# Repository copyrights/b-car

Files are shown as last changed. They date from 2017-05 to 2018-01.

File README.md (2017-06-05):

# b-car
Take a classic Big Bobby Car, cut a hole in the underbody, drill some more holes, put some RGB-LEDs, buttons and a sensor through holes, place a battery and a circuit board inside and you ready to go.

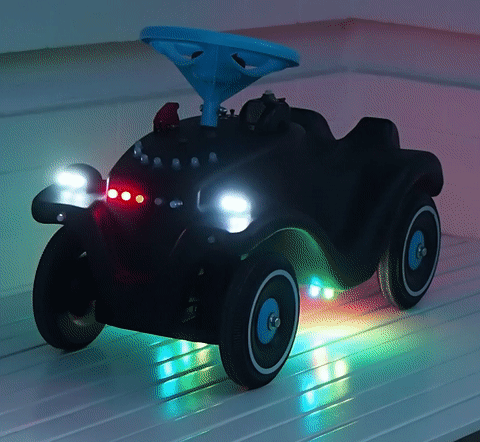
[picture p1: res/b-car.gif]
b-car GIF
   

You could use project as base for your own Bobby Car, bicycle or what ever. Get creative.
## Features
* Knight Rider like front row
* full control
  * connect up to 10 button (+power button)
  * program via USB
  * write our own program with Arduino IDE 1.6.5+ (Arduino 1.6.5r2 - NOT 1.6.6 or 1.6.7 strongly recommended) 
* tachometer
  * three colors
  * show real speed via photo sensor at a tire
* car basics
  * low beam
  * high beam 
  * back light
  * turn lights
* flash light
* police beacon light an front flash
* rainbow mode

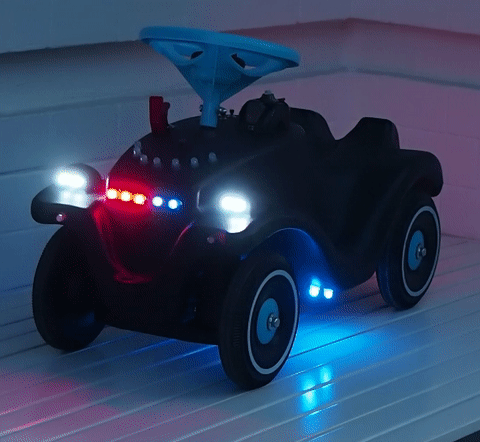
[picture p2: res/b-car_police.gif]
b-car police mode GIF
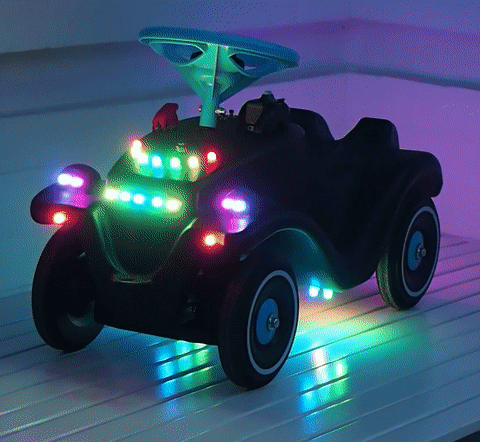
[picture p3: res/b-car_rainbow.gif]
b-car rainbow GIF
 
## Hardware
### Circuit 

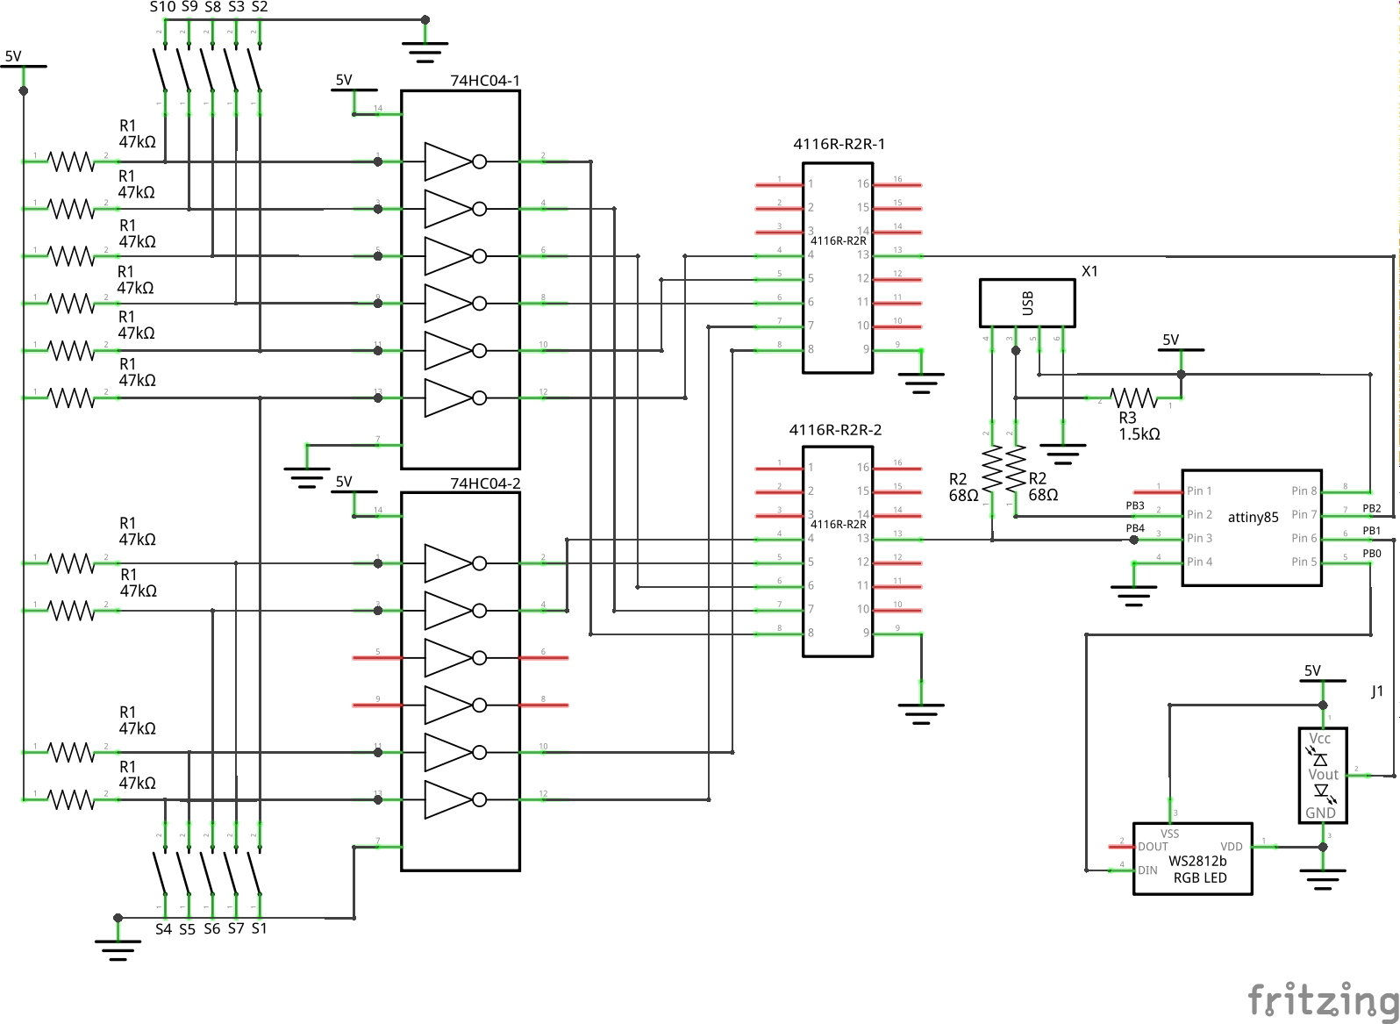
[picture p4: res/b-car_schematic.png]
schematic


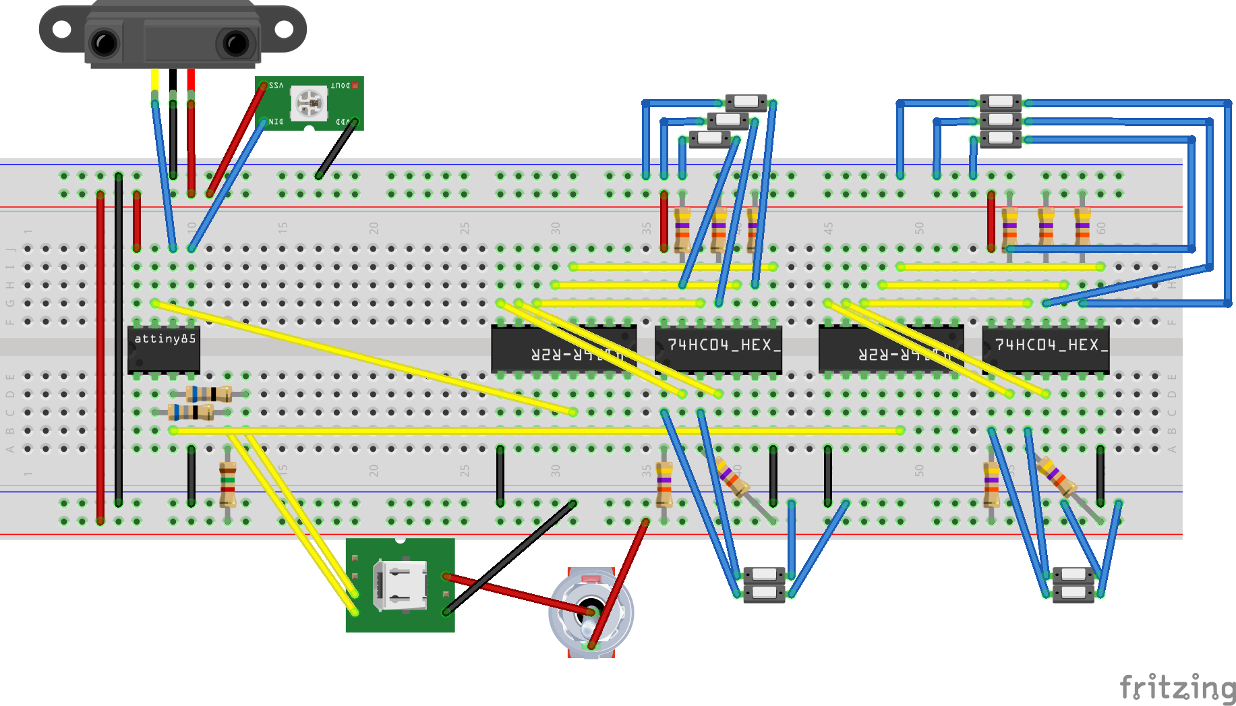
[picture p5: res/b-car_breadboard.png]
bread board


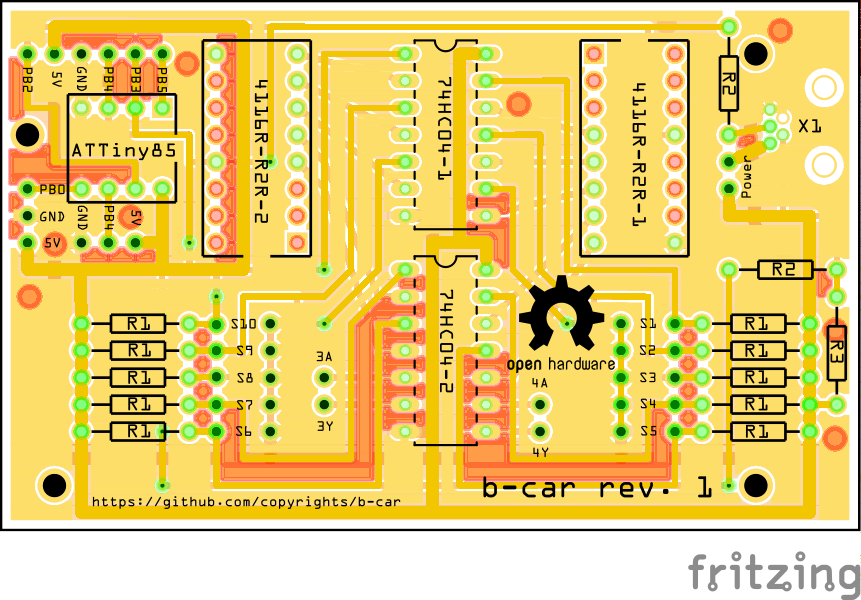
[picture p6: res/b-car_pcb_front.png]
pcb front side


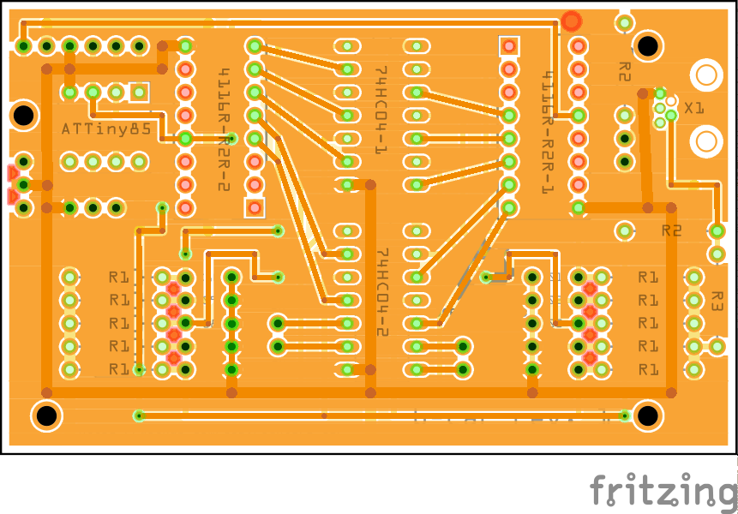
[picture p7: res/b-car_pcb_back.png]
pcb back side


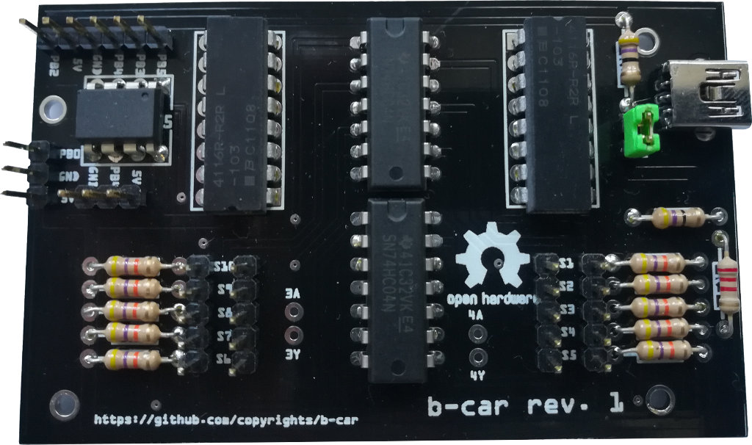
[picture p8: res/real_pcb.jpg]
final board

### Bobby Car 

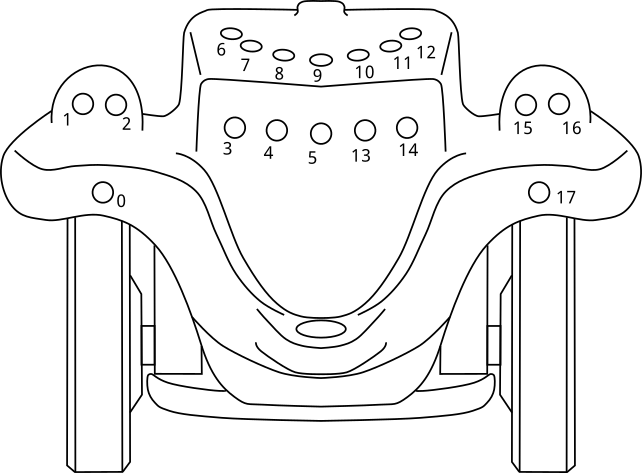
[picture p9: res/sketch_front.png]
sketch front


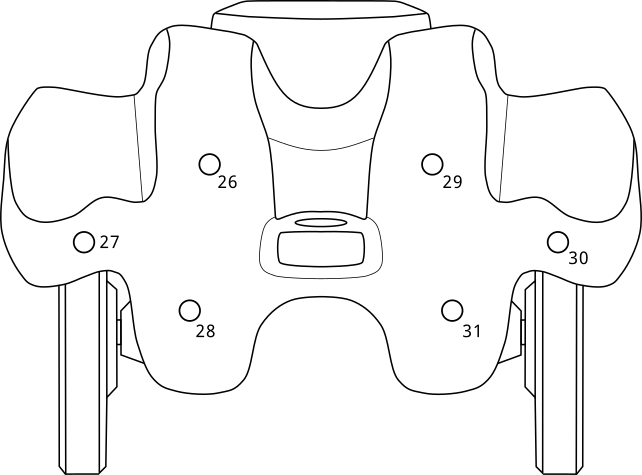
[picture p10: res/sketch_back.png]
Sketch front


## Software
The b-car runs the [micronucleus tiny85](https://github.com/micronucleus/micronucleus) bootloader.

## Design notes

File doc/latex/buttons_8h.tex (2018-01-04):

\hypertarget{buttons_8h}{}\section{buttons.\+h File Reference}
\label{buttons_8h}\index{buttons.\+h@{buttons.\+h}}
{\ttfamily \#include \char`\"{}config.\+h\char`\"{}}\\*
Include dependency graph for buttons.\+h\+:\nopagebreak
\begin{figure}[H]
\begin{center}
\leavevmode
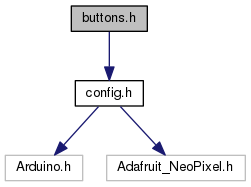
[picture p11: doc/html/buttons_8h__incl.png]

\end{center}
\end{figure}
This graph shows which files directly or indirectly include this file\+:\nopagebreak
\begin{figure}[H]
\begin{center}
\leavevmode
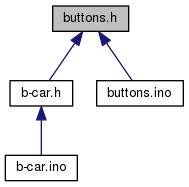
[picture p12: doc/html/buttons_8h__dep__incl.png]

\end{center}
\end{figure}
\subsection*{Functions}
\begin{DoxyCompactItemize}
\item 
void \hyperlink{buttons_8h_af32fa88edc93b34e25f058e331ea1134}{update\+Buttons} ()
\begin{DoxyCompactList}\small\item\em Read button state and calculate stable button state. \end{DoxyCompactList}\item 
bool \hyperlink{buttons_8h_ad4a8f6035320735a6ed69364c0f29d63}{button\+State} (uint16\+\_\+t mask)
\begin{DoxyCompactList}\small\item\em Returns the state of a button as boolean. \end{DoxyCompactList}\item 
uint16\+\_\+t \hyperlink{buttons_8h_a5421761bb5d1c3470d3b17196a438c80}{readr2r} (int pin)
\begin{DoxyCompactList}\small\item\em Calculated the current button state as a 5 bit mask. \end{DoxyCompactList}\item 
uint16\+\_\+t \hyperlink{buttons_8h_a0ce7c5a698df341a0f3882378518f562}{debounce} (uint16\+\_\+t curbuttons)
\begin{DoxyCompactList}\small\item\em Debounce button presses of the R-\/2R resistor ladder network. \end{DoxyCompactList}\item 
void \hyperlink{buttons_8h_a66c6a02c014dc9acd3af0c816a70fad8}{updintr} (uint16\+\_\+t state)
\begin{DoxyCompactList}\small\item\em Update the simulated interrupts of the R-\/2R resistor ladder network. \end{DoxyCompactList}\item 
uint16\+\_\+t \hyperlink{buttons_8h_a9b1decfe9116af4b8853a02aebfa1d14}{get\+Rising} (uint16\+\_\+t mask)
\begin{DoxyCompactList}\small\item\em Get simulated rising edge interrupt(s) for simulated interrupt service routine. \end{DoxyCompactList}\item 
uint16\+\_\+t \hyperlink{buttons_8h_a2971d62e0d7420f71836fb86e0fce92f}{get\+Falling} (uint16\+\_\+t mask)
\begin{DoxyCompactList}\small\item\em Get simulated falling edge interrupt(s) for simulated interrupt service routine. \end{DoxyCompactList}\end{DoxyCompactItemize}
\subsection*{Variables}
\begin{DoxyCompactItemize}
\item 
uint16\+\_\+t \hyperlink{group__buttons_gac23a04180ca7609f571853499faae915}{lastbuttons}
\begin{DoxyCompactList}\small\item\em Last read of button pressed. \end{DoxyCompactList}\item 
uint16\+\_\+t \hyperlink{buttons_8h_aca8bc953fb5340b58c9403b3bf8bbd8e}{stablebuttons}
\begin{DoxyCompactList}\small\item\em Pressed Buttons after debounce. \end{DoxyCompactList}\item 
uint16\+\_\+t \hyperlink{buttons_8h_ac52f8abe18e87b9ce8cdba2e27bbbf02}{buttonstore}
\begin{DoxyCompactList}\small\item\em Stores push buttons as simulated toggle buttons. \end{DoxyCompactList}\item 
uint16\+\_\+t \hyperlink{buttons_8h_afa19e52bd127439ef22ade9f91753386}{buttonstate}
\begin{DoxyCompactList}\small\item\em Stores current button state with simulated toggle buttons included. \end{DoxyCompactList}\item 
uint16\+\_\+t \hyperlink{buttons_8h_acc4c256fa5e75c09f1b3a669d45485ec}{rising}
\begin{DoxyCompactList}\small\item\em Stores simulated interrupts for rising edge. \end{DoxyCompactList}\item 
uint16\+\_\+t \hyperlink{buttons_8h_a1861b594f36400f6c17b1f65b2565816}{falling}
\begin{DoxyCompactList}\small\item\em Stores simulated interrupts for falling edge. \end{DoxyCompactList}\item 
uint16\+\_\+t \hyperlink{buttons_8h_a541db091bf54e0a51180f3666e5a2ce2}{rfilter}
\begin{DoxyCompactList}\small\item\em Filter for simulated interrupts for rising edge. \end{DoxyCompactList}\item 
uint16\+\_\+t \hyperlink{buttons_8h_aaa75cede053f94cf46d7420556af1505}{ffilter}
\begin{DoxyCompactList}\small\item\em Filter for simulated interrupts for falling edge. \end{DoxyCompactList}\item 
unsigned long \hyperlink{buttons_8h_a94921f7ca95d518d3deabb1da432c2fb}{dtime}
\begin{DoxyCompactList}\small\item\em Store the time of the last debounce to calculate delta time to next debounce. \end{DoxyCompactList}\end{DoxyCompactItemize}

\subsection{Function Documentation}
\index{buttons.\+h@{buttons.\+h}!button\+State@{button\+State}}
\index{button\+State@{button\+State}!buttons.\+h@{buttons.\+h}}
\subsubsection[{\texorpdfstring{button\+State(uint16\+\_\+t mask)}{buttonState(uint16_t mask)}}]{\setlength{\rightskip}{0pt plus 5cm}bool button\+State (
\begin{DoxyParamCaption}
\item[{uint16\+\_\+t}]{mask}
\end{DoxyParamCaption}
)}\hypertarget{buttons_8h_ad4a8f6035320735a6ed69364c0f29d63}{}\label{buttons_8h_ad4a8f6035320735a6ed69364c0f29d63}

Returns the state of a button as boolean. 

\begin{DoxyParams}{Parameters}
{\em mask} & Button of interested. \\
\hline
\end{DoxyParams}
\begin{DoxyReturn}{Returns}
Returns true, if button is pressed. Returns false, if it is not pressed. 
\end{DoxyReturn}

Definition at line 50 of file buttons.\+ino.

\index{buttons.\+h@{buttons.\+h}!debounce@{debounce}}
\index{debounce@{debounce}!buttons.\+h@{buttons.\+h}}
\subsubsection[{\texorpdfstring{debounce(uint16\+\_\+t curbuttons)}{debounce(uint16_t curbuttons)}}]{\setlength{\rightskip}{0pt plus 5cm}uint16\+\_\+t debounce (
\begin{DoxyParamCaption}
\item[{uint16\+\_\+t}]{curbuttons}
\end{DoxyParamCaption}
)}\hypertarget{buttons_8h_a0ce7c5a698df341a0f3882378518f562}{}\label{buttons_8h_a0ce7c5a698df341a0f3882378518f562}

Debounce button presses of the R-\/2R resistor ladder network. 

\begin{DoxyParams}{Parameters}
{\em curbuttons} & Bit mask of current button state. \\
\hline
\end{DoxyParams}
\begin{DoxyReturn}{Returns}
Bit mask of debounced button state. 
\end{DoxyReturn}

Definition at line 79 of file buttons.\+ino.

\index{buttons.\+h@{buttons.\+h}!get\+Falling@{get\+Falling}}
\index{get\+Falling@{get\+Falling}!buttons.\+h@{buttons.\+h}}
\subsubsection[{\texorpdfstring{get\+Falling(uint16\+\_\+t mask)}{getFalling(uint16_t mask)}}]{\setlength{\rightskip}{0pt plus 5cm}uint16\+\_\+t get\+Falling (
\begin{DoxyParamCaption}
\item[{uint16\+\_\+t}]{mask}
\end{DoxyParamCaption}
)}\hypertarget{buttons_8h_a2971d62e0d7420f71836fb86e0fce92f}{}\label{buttons_8h_a2971d62e0d7420f71836fb86e0fce92f}

Get simulated falling edge interrupt(s) for simulated interrupt service routine. 

\begin{DoxyParams}{Parameters}
{\em mask} & Button(s) of interest. \\
\hline
\end{DoxyParams}
\begin{DoxyReturn}{Returns}
Bit mask of interrupt(s). 
\end{DoxyReturn}

Definition at line 129 of file buttons.\+ino.

\index{buttons.\+h@{buttons.\+h}!get\+Rising@{get\+Rising}}
\index{get\+Rising@{get\+Rising}!buttons.\+h@{buttons.\+h}}
\subsubsection[{\texorpdfstring{get\+Rising(uint16\+\_\+t mask)}{getRising(uint16_t mask)}}]{\setlength{\rightskip}{0pt plus 5cm}uint16\+\_\+t get\+Rising (
\begin{DoxyParamCaption}
\item[{uint16\+\_\+t}]{mask}
\end{DoxyParamCaption}
)}\hypertarget{buttons_8h_a9b1decfe9116af4b8853a02aebfa1d14}{}\label{buttons_8h_a9b1decfe9116af4b8853a02aebfa1d14}

Get simulated rising edge interrupt(s) for simulated interrupt service routine. 

\begin{DoxyParams}{Parameters}
{\em mask} & Button(s) of interest. \\
\hline
\end{DoxyParams}
\begin{DoxyReturn}{Returns}
Bit mask of interrupt(s). 
\end{DoxyReturn}

Definition at line 115 of file buttons.\+ino.

\index{buttons.\+h@{buttons.\+h}!readr2r@{readr2r}}
\index{readr2r@{readr2r}!buttons.\+h@{buttons.\+h}}
\subsubsection[{\texorpdfstring{readr2r(int pin)}{readr2r(int pin)}}]{\setlength{\rightskip}{0pt plus 5cm}uint16\+\_\+t readr2r (
\begin{DoxyParamCaption}
\item[{int}]{pin}
\end{DoxyParamCaption}
)}\hypertarget{buttons_8h_a5421761bb5d1c3470d3b17196a438c80}{}\label{buttons_8h_a5421761bb5d1c3470d3b17196a438c80}

Calculated the current button state as a 5 bit mask. 

\begin{DoxyParams}{Parameters}
{\em pin} & Analog input pin connected to a R-\/2R resistor ladder network. \\
\hline
\end{DoxyParams}
\begin{DoxyReturn}{Returns}
Current button state as 5 bit mask. 
\end{DoxyReturn}

Definition at line 61 of file buttons.\+ino.

\index{buttons.\+h@{buttons.\+h}!update\+Buttons@{update\+Buttons}}
\index{update\+Buttons@{update\+Buttons}!buttons.\+h@{buttons.\+h}}
\subsubsection[{\texorpdfstring{update\+Buttons()}{updateButtons()}}]{\setlength{\rightskip}{0pt plus 5cm}void update\+Buttons (
\begin{DoxyParamCaption}
{}
\end{DoxyParamCaption}
)}\hypertarget{buttons_8h_af32fa88edc93b34e25f058e331ea1134}{}\label{buttons_8h_af32fa88edc93b34e25f058e331ea1134}

Read button state and calculate stable button state. 

Definition at line 33 of file buttons.\+ino.

\index{buttons.\+h@{buttons.\+h}!updintr@{updintr}}
\index{updintr@{updintr}!buttons.\+h@{buttons.\+h}}
\subsubsection[{\texorpdfstring{updintr(uint16\+\_\+t state)}{updintr(uint16_t state)}}]{\setlength{\rightskip}{0pt plus 5cm}void updintr (
\begin{DoxyParamCaption}
\item[{uint16\+\_\+t}]{state}
\end{DoxyParamCaption}
)}\hypertarget{buttons_8h_a66c6a02c014dc9acd3af0c816a70fad8}{}\label{buttons_8h_a66c6a02c014dc9acd3af0c816a70fad8}

Update the simulated interrupts of the R-\/2R resistor ladder network. 

\begin{DoxyParams}{Parameters}
{\em state} & Bit mask of current button state. \\
\hline
\end{DoxyParams}

Definition at line 101 of file buttons.\+ino.

\subsection{Variable Documentation}
\index{buttons.\+h@{buttons.\+h}!buttonstate@{buttonstate}}
\index{buttonstate@{buttonstate}!buttons.\+h@{buttons.\+h}}
\subsubsection[{\texorpdfstring{buttonstate}{buttonstate}}]{\setlength{\rightskip}{0pt plus 5cm}uint16\+\_\+t buttonstate}\hypertarget{buttons_8h_afa19e52bd127439ef22ade9f91753386}{}\label{buttons_8h_afa19e52bd127439ef22ade9f91753386}

Stores current button state with simulated toggle buttons included. 

Definition at line 20 of file buttons.\+ino.

\index{buttons.\+h@{buttons.\+h}!buttonstore@{buttonstore}}
\index{buttonstore@{buttonstore}!buttons.\+h@{buttons.\+h}}
\subsubsection[{\texorpdfstring{buttonstore}{buttonstore}}]{\setlength{\rightskip}{0pt plus 5cm}uint16\+\_\+t buttonstore}\hypertarget{buttons_8h_ac52f8abe18e87b9ce8cdba2e27bbbf02}{}\label{buttons_8h_ac52f8abe18e87b9ce8cdba2e27bbbf02}

Stores push buttons as simulated toggle buttons. 

Definition at line 18 of file buttons.\+ino.

\index{buttons.\+h@{buttons.\+h}!dtime@{dtime}}
\index{dtime@{dtime}!buttons.\+h@{buttons.\+h}}
\subsubsection[{\texorpdfstring{dtime}{dtime}}]{\setlength{\rightskip}{0pt plus 5cm}unsigned long dtime}\hypertarget{buttons_8h_a94921f7ca95d518d3deabb1da432c2fb}{}\label{buttons_8h_a94921f7ca95d518d3deabb1da432c2fb}

Store the time of the last debounce to calculate delta time to next debounce. 

Definition at line 30 of file buttons.\+ino.

\index{buttons.\+h@{buttons.\+h}!falling@{falling}}
\index{falling@{falling}!buttons.\+h@{buttons.\+h}}
\subsubsection[{\texorpdfstring{falling}{falling}}]{\setlength{\rightskip}{0pt plus 5cm}uint16\+\_\+t falling}\hypertarget{buttons_8h_a1861b594f36400f6c17b1f65b2565816}{}\label{buttons_8h_a1861b594f36400f6c17b1f65b2565816}

Stores simulated interrupts for falling edge. 

Definition at line 24 of file buttons.\+ino.

\index{buttons.\+h@{buttons.\+h}!ffilter@{ffilter}}
\index{ffilter@{ffilter}!buttons.\+h@{buttons.\+h}}
\subsubsection[{\texorpdfstring{ffilter}{ffilter}}]{\setlength{\rightskip}{0pt plus 5cm}uint16\+\_\+t ffilter}\hypertarget{buttons_8h_aaa75cede053f94cf46d7420556af1505}{}\label{buttons_8h_aaa75cede053f94cf46d7420556af1505}

Filter for simulated interrupts for falling edge. 

Definition at line 28 of file buttons.\+ino.

\index{buttons.\+h@{buttons.\+h}!rfilter@{rfilter}}
\index{rfilter@{rfilter}!buttons.\+h@{buttons.\+h}}
\subsubsection[{\texorpdfstring{rfilter}{rfilter}}]{\setlength{\rightskip}{0pt plus 5cm}uint16\+\_\+t rfilter}\hypertarget{buttons_8h_a541db091bf54e0a51180f3666e5a2ce2}{}\label{buttons_8h_a541db091bf54e0a51180f3666e5a2ce2}

Filter for simulated interrupts for rising edge. 

Definition at line 26 of file buttons.\+ino.

\index{buttons.\+h@{buttons.\+h}!rising@{rising}}
\index{rising@{rising}!buttons.\+h@{buttons.\+h}}
\subsubsection[{\texorpdfstring{rising}{rising}}]{\setlength{\rightskip}{0pt plus 5cm}uint16\+\_\+t rising}\hypertarget{buttons_8h_acc4c256fa5e75c09f1b3a669d45485ec}{}\label{buttons_8h_acc4c256fa5e75c09f1b3a669d45485ec}

Stores simulated interrupts for rising edge. 

Definition at line 22 of file buttons.\+ino.

\index{buttons.\+h@{buttons.\+h}!stablebuttons@{stablebuttons}}
\index{stablebuttons@{stablebuttons}!buttons.\+h@{buttons.\+h}}
\subsubsection[{\texorpdfstring{stablebuttons}{stablebuttons}}]{\setlength{\rightskip}{0pt plus 5cm}uint16\+\_\+t stablebuttons}\hypertarget{buttons_8h_aca8bc953fb5340b58c9403b3bf8bbd8e}{}\label{buttons_8h_aca8bc953fb5340b58c9403b3bf8bbd8e}

Pressed Buttons after debounce. 

Definition at line 16 of file buttons.\+ino.

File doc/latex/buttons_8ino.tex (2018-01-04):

\hypertarget{buttons_8ino}{}\section{buttons.\+ino File Reference}
\label{buttons_8ino}\index{buttons.\+ino@{buttons.\+ino}}

Use two R-\/2R resistor ladder networks to connect up to 10 buttons on two analog inputs.  

{\ttfamily \#include \char`\"{}buttons.\+h\char`\"{}}\\*
Include dependency graph for buttons.\+ino\+:\nopagebreak
\begin{figure}[H]
\begin{center}
\leavevmode
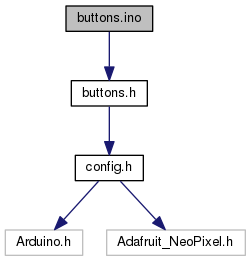
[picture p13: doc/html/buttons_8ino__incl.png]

\end{center}
\end{figure}
\begin{DoxyCompactItemize}
\item 
uint16\+\_\+t \hyperlink{group__buttons_gac23a04180ca7609f571853499faae915}{lastbuttons} = 0
\begin{DoxyCompactList}\small\item\em Last read of button pressed. \end{DoxyCompactList}\item 
uint16\+\_\+t \hyperlink{group__buttons_gaca8bc953fb5340b58c9403b3bf8bbd8e}{stablebuttons} = 0
\begin{DoxyCompactList}\small\item\em Pressed Buttons after debounce. \end{DoxyCompactList}\item 
uint16\+\_\+t \hyperlink{group__buttons_gac52f8abe18e87b9ce8cdba2e27bbbf02}{buttonstore} = \hyperlink{group__buttons_ga77a6549a849f9a9472a367e4148289b7}{T\+O\+G\+G\+L\+E\+M\+A\+SK}
\begin{DoxyCompactList}\small\item\em Stores push buttons as simulated toggle buttons. \end{DoxyCompactList}\item 
uint16\+\_\+t \hyperlink{group__buttons_gafa19e52bd127439ef22ade9f91753386}{buttonstate} = 0
\begin{DoxyCompactList}\small\item\em Stores current button state with simulated toggle buttons included. \end{DoxyCompactList}\item 
uint16\+\_\+t \hyperlink{group__buttons_gacc4c256fa5e75c09f1b3a669d45485ec}{rising} = 0
\begin{DoxyCompactList}\small\item\em Stores simulated interrupts for rising edge. \end{DoxyCompactList}\item 
uint16\+\_\+t \hyperlink{group__buttons_ga1861b594f36400f6c17b1f65b2565816}{falling} = 0
\begin{DoxyCompactList}\small\item\em Stores simulated interrupts for falling edge. \end{DoxyCompactList}\item 
uint16\+\_\+t \hyperlink{group__buttons_ga541db091bf54e0a51180f3666e5a2ce2}{rfilter} = 0
\begin{DoxyCompactList}\small\item\em Filter for simulated interrupts for rising edge. \end{DoxyCompactList}\item 
uint16\+\_\+t \hyperlink{group__buttons_gaaa75cede053f94cf46d7420556af1505}{ffilter} = 0
\begin{DoxyCompactList}\small\item\em Filter for simulated interrupts for falling edge. \end{DoxyCompactList}\item 
unsigned long \hyperlink{group__buttons_ga94921f7ca95d518d3deabb1da432c2fb}{dtime} = 0
\begin{DoxyCompactList}\small\item\em Store the time of the last debounce to calculate delta time to next debounce. \end{DoxyCompactList}\item 
void \hyperlink{group__buttons_gaf32fa88edc93b34e25f058e331ea1134}{update\+Buttons} ()
\begin{DoxyCompactList}\small\item\em Read button state and calculate stable button state. \end{DoxyCompactList}\item 
bool \hyperlink{group__buttons_gad4a8f6035320735a6ed69364c0f29d63}{button\+State} (uint16\+\_\+t mask)
\begin{DoxyCompactList}\small\item\em Returns the state of a button as boolean. \end{DoxyCompactList}\item 
uint16\+\_\+t \hyperlink{group__buttons_ga5421761bb5d1c3470d3b17196a438c80}{readr2r} (int pin)
\begin{DoxyCompactList}\small\item\em Calculated the current button state as a 5 bit mask. \end{DoxyCompactList}\item 
uint16\+\_\+t \hyperlink{group__buttons_ga0ce7c5a698df341a0f3882378518f562}{debounce} (uint16\+\_\+t curbuttons)
\begin{DoxyCompactList}\small\item\em Debounce button presses of the R-\/2R resistor ladder network. \end{DoxyCompactList}\item 
void \hyperlink{group__buttons_ga66c6a02c014dc9acd3af0c816a70fad8}{updintr} (uint16\+\_\+t state)
\begin{DoxyCompactList}\small\item\em Update the simulated interrupts of the R-\/2R resistor ladder network. \end{DoxyCompactList}\item 
uint16\+\_\+t \hyperlink{group__buttons_ga9b1decfe9116af4b8853a02aebfa1d14}{get\+Rising} (uint16\+\_\+t mask)
\begin{DoxyCompactList}\small\item\em Get simulated rising edge interrupt(s) for simulated interrupt service routine. \end{DoxyCompactList}\item 
uint16\+\_\+t \hyperlink{group__buttons_ga2971d62e0d7420f71836fb86e0fce92f}{get\+Falling} (uint16\+\_\+t mask)
\begin{DoxyCompactList}\small\item\em Get simulated falling edge interrupt(s) for simulated interrupt service routine. \end{DoxyCompactList}\end{DoxyCompactItemize}

\subsection{Detailed Description}
Use two R-\/2R resistor ladder networks to connect up to 10 buttons on two analog inputs. 

\begin{DoxyAuthor}{Author}
copyrights
\end{DoxyAuthor}
\begin{DoxySeeAlso}{See also}
\href{https://en.wikipedia.org/wiki/Resistor_ladder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}{\tt https\+://en.\+wikipedia.\+org/wiki/\+Resistor\+\_\+ladder\#\+R.\+E2.\+80.\+932\+R\+\_\+resistor\+\_\+ladder\+\_\+network\+\_\+.\+28digital\+\_\+to\+\_\+analog\+\_\+conversion.\+29} 
\end{DoxySeeAlso}

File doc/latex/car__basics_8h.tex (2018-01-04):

\hypertarget{car__basics_8h}{}\section{car\+\_\+basics.\+h File Reference}
\label{car__basics_8h}\index{car\+\_\+basics.\+h@{car\+\_\+basics.\+h}}
{\ttfamily \#include \char`\"{}config.\+h\char`\"{}}\\*
Include dependency graph for car\+\_\+basics.\+h\+:\nopagebreak
\begin{figure}[H]
\begin{center}
\leavevmode
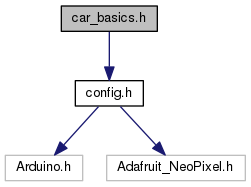
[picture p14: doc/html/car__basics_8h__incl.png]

\end{center}
\end{figure}
This graph shows which files directly or indirectly include this file\+:\nopagebreak
\begin{figure}[H]
\begin{center}
\leavevmode
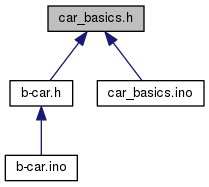
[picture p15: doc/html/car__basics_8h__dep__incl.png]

\end{center}
\end{figure}
\subsection*{Functions}
\begin{DoxyCompactItemize}
\item 
void \hyperlink{car__basics_8h_aca3b725ebee32d3719a9c02b41002ea3}{turn\+\_\+right} ()
\begin{DoxyCompactList}\small\item\em Activate right turn lights. \end{DoxyCompactList}\item 
void \hyperlink{car__basics_8h_a0565ad7a822d9d334bb50c088af22361}{turn\+\_\+left} ()
\begin{DoxyCompactList}\small\item\em Activate left turn lights. \end{DoxyCompactList}\item 
void \hyperlink{car__basics_8h_a6b1fd674445dd1c654dfe8b8b65f168e}{beam} (unsigned long state)
\begin{DoxyCompactList}\small\item\em Activate low beam or high beam. \end{DoxyCompactList}\item 
void \hyperlink{car__basics_8h_a29d5eff542aae0196b8e84b8a752e1df}{low\+\_\+beam} (bool on)
\item 
void \hyperlink{car__basics_8h_a1088d06b4ab015d579e0ac2510d39f25}{high\+\_\+beam} (bool on)
\item 
void \hyperlink{car__basics_8h_ac7295d1018b2b948084ba5dbacf09d74}{tacho} ()
\begin{DoxyCompactList}\small\item\em Display the current speed on tacho\+\_\+row L\+E\+Ds. \end{DoxyCompactList}\item 
void \hyperlink{car__basics_8h_affb7c011f82f3fb47b39ebb2713a1cd8}{flash} ()
\begin{DoxyCompactList}\small\item\em Flash light. \end{DoxyCompactList}\item 
void \hyperlink{car__basics_8h_a1ac48972153097ad7a16fffc032fc5f1}{brakelight} ()
\begin{DoxyCompactList}\small\item\em Brake light. \end{DoxyCompactList}\end{DoxyCompactItemize}

\subsection{Function Documentation}
\index{car\+\_\+basics.\+h@{car\+\_\+basics.\+h}!beam@{beam}}
\index{beam@{beam}!car\+\_\+basics.\+h@{car\+\_\+basics.\+h}}
\subsubsection[{\texorpdfstring{beam(unsigned long state)}{beam(unsigned long state)}}]{\setlength{\rightskip}{0pt plus 5cm}void beam (
\begin{DoxyParamCaption}
\item[{unsigned long}]{state}
\end{DoxyParamCaption}
)}\hypertarget{car__basics_8h_a6b1fd674445dd1c654dfe8b8b65f168e}{}\label{car__basics_8h_a6b1fd674445dd1c654dfe8b8b65f168e}

Activate low beam or high beam. 

\begin{DoxyRefDesc}{Todo}
\item[\hyperlink{todo__todo000002}{Todo}]Rewrite as all L\+E\+Ds get clear at the beginning of the main loop \end{DoxyRefDesc}

Definition at line 59 of file car\+\_\+basics.\+ino.

\index{car\+\_\+basics.\+h@{car\+\_\+basics.\+h}!brakelight@{brakelight}}
\index{brakelight@{brakelight}!car\+\_\+basics.\+h@{car\+\_\+basics.\+h}}
\subsubsection[{\texorpdfstring{brakelight()}{brakelight()}}]{\setlength{\rightskip}{0pt plus 5cm}void brakelight (
\begin{DoxyParamCaption}
{}
\end{DoxyParamCaption}
)}\hypertarget{car__basics_8h_a1ac48972153097ad7a16fffc032fc5f1}{}\label{car__basics_8h_a1ac48972153097ad7a16fffc032fc5f1}

Brake light. 

Put \hyperlink{group__deployment_ga3a2101866267bf0af2559a241cdb7cc6}{back\+\_\+light\+\_\+row} to \hyperlink{group__car_ga95743a8e9ccb3be5a627dd9322806751}{B\+R\+A\+K\+E\+L\+I\+G\+HT}. 

Definition at line 184 of file car\+\_\+basics.\+ino.

\index{car\+\_\+basics.\+h@{car\+\_\+basics.\+h}!flash@{flash}}
\index{flash@{flash}!car\+\_\+basics.\+h@{car\+\_\+basics.\+h}}
\subsubsection[{\texorpdfstring{flash()}{flash()}}]{\setlength{\rightskip}{0pt plus 5cm}void flash (
\begin{DoxyParamCaption}
{}
\end{DoxyParamCaption}
)}\hypertarget{car__basics_8h_affb7c011f82f3fb47b39ebb2713a1cd8}{}\label{car__basics_8h_affb7c011f82f3fb47b39ebb2713a1cd8}

Flash light. 

Put \hyperlink{group__deployment_ga8b165874b487053cb404215a7f42e33e}{high\+\_\+beam\+\_\+row}, \hyperlink{group__deployment_ga848556a6e145736d917b4f0a67ee60ae}{front\+\_\+row} and \hyperlink{group__deployment_ga3a2101866267bf0af2559a241cdb7cc6}{back\+\_\+light\+\_\+row} to \hyperlink{group__car_ga3f561f12573270e4b5329bc5930ad20f}{H\+I\+G\+H\+B\+E\+AM}. 

Definition at line 164 of file car\+\_\+basics.\+ino.

\index{car\+\_\+basics.\+h@{car\+\_\+basics.\+h}!high\+\_\+beam@{high\+\_\+beam}}
\index{high\+\_\+beam@{high\+\_\+beam}!car\+\_\+basics.\+h@{car\+\_\+basics.\+h}}
\subsubsection[{\texorpdfstring{high\+\_\+beam(bool on)}{high_beam(bool on)}}]{\setlength{\rightskip}{0pt plus 5cm}void high\+\_\+beam (
\begin{DoxyParamCaption}
\item[{bool}]{on}
\end{DoxyParamCaption}
)}\hypertarget{car__basics_8h_a1088d06b4ab015d579e0ac2510d39f25}{}\label{car__basics_8h_a1088d06b4ab015d579e0ac2510d39f25}

Definition at line 91 of file car\+\_\+basics.\+ino.

\index{car\+\_\+basics.\+h@{car\+\_\+basics.\+h}!low\+\_\+beam@{low\+\_\+beam}}
\index{low\+\_\+beam@{low\+\_\+beam}!car\+\_\+basics.\+h@{car\+\_\+basics.\+h}}
\subsubsection[{\texorpdfstring{low\+\_\+beam(bool on)}{low_beam(bool on)}}]{\setlength{\rightskip}{0pt plus 5cm}void low\+\_\+beam (
\begin{DoxyParamCaption}
\item[{bool}]{on}
\end{DoxyParamCaption}
)}\hypertarget{car__basics_8h_a29d5eff542aae0196b8e84b8a752e1df}{}\label{car__basics_8h_a29d5eff542aae0196b8e84b8a752e1df}

Definition at line 73 of file car\+\_\+basics.\+ino.

\index{car\+\_\+basics.\+h@{car\+\_\+basics.\+h}!tacho@{tacho}}
\index{tacho@{tacho}!car\+\_\+basics.\+h@{car\+\_\+basics.\+h}}
\subsubsection[{\texorpdfstring{tacho()}{tacho()}}]{\setlength{\rightskip}{0pt plus 5cm}void tacho (
\begin{DoxyParamCaption}
{}
\end{DoxyParamCaption}
)}\hypertarget{car__basics_8h_ac7295d1018b2b948084ba5dbacf09d74}{}\label{car__basics_8h_ac7295d1018b2b948084ba5dbacf09d74}

Display the current speed on tacho\+\_\+row L\+E\+Ds. 

It is show from left to right in three different color.

\begin{DoxyItemize}
\item Green (0x001100)\+: low speed
\item Orange (0x110800)\+: medium speed
\item Red (0x110000)\+: ludicrous speed
\end{DoxyItemize}

The function \hyperlink{speed_8h_afc7b1718f9b23966dfed24056f67996f}{getspeed()} returns an unsigned integer with a step size of 1 equals 0.\+4302 km/h. As the speed is displayed in three color the maximum speed should be dividable by three.

The integer value 30 -\/$>$ 12.\+9 km/h. 12.\+9 km/h should be enough for small children. If you have a older child or use this for different purposes (e.\+g. a bicycle), the maximum speed should be higher.

30/3 = 10 -\/$>$ speed $\ast$ count of tachometer L\+E\+Ds / 10 \begin{DoxySeeAlso}{See also}
\hyperlink{speed_8h_afc7b1718f9b23966dfed24056f67996f}{getspeed()} 
\end{DoxySeeAlso}

Definition at line 129 of file car\+\_\+basics.\+ino.

\index{car\+\_\+basics.\+h@{car\+\_\+basics.\+h}!turn\+\_\+left@{turn\+\_\+left}}
\index{turn\+\_\+left@{turn\+\_\+left}!car\+\_\+basics.\+h@{car\+\_\+basics.\+h}}
\subsubsection[{\texorpdfstring{turn\+\_\+left()}{turn_left()}}]{\setlength{\rightskip}{0pt plus 5cm}void turn\+\_\+left (
\begin{DoxyParamCaption}
{}
\end{DoxyParamCaption}
)}\hypertarget{car__basics_8h_a0565ad7a822d9d334bb50c088af22361}{}\label{car__basics_8h_a0565ad7a822d9d334bb50c088af22361}

Activate left turn lights. 

Definition at line 42 of file car\+\_\+basics.\+ino.

\index{car\+\_\+basics.\+h@{car\+\_\+basics.\+h}!turn\+\_\+right@{turn\+\_\+right}}
\index{turn\+\_\+right@{turn\+\_\+right}!car\+\_\+basics.\+h@{car\+\_\+basics.\+h}}
\subsubsection[{\texorpdfstring{turn\+\_\+right()}{turn_right()}}]{\setlength{\rightskip}{0pt plus 5cm}void turn\+\_\+right (
\begin{DoxyParamCaption}
{}
\end{DoxyParamCaption}
)}\hypertarget{car__basics_8h_aca3b725ebee32d3719a9c02b41002ea3}{}\label{car__basics_8h_aca3b725ebee32d3719a9c02b41002ea3}

Activate right turn lights. 

Definition at line 27 of file car\+\_\+basics.\+ino.

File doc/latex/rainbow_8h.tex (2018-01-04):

\hypertarget{rainbow_8h}{}\section{rainbow.\+h File Reference}
\label{rainbow_8h}\index{rainbow.\+h@{rainbow.\+h}}
{\ttfamily \#include \char`\"{}config.\+h\char`\"{}}\\*
Include dependency graph for rainbow.\+h\+:\nopagebreak
\begin{figure}[H]
\begin{center}
\leavevmode
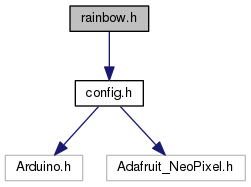
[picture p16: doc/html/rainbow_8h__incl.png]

\end{center}
\end{figure}
This graph shows which files directly or indirectly include this file\+:\nopagebreak
\begin{figure}[H]
\begin{center}
\leavevmode
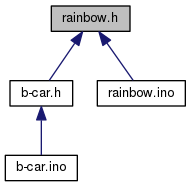
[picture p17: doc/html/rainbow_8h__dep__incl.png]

\end{center}
\end{figure}
\subsection*{Functions}
\begin{DoxyCompactItemize}
\item 
void \hyperlink{rainbow_8h_a51e30a1c423190e50127c6651c991612}{rainbowmode} ()
\item 
void \hyperlink{rainbow_8h_a3656f41cfe48a0bf63e63099673ac4c4}{underbody\+\_\+rb} ()
\item 
void \hyperlink{rainbow_8h_a80198b192c269a2b71cfa41654a3aafd}{rainbow} (byte led, byte pos, byte distance)
\end{DoxyCompactItemize}

\subsection{Function Documentation}
\index{rainbow.\+h@{rainbow.\+h}!rainbow@{rainbow}}
\index{rainbow@{rainbow}!rainbow.\+h@{rainbow.\+h}}
\subsubsection[{\texorpdfstring{rainbow(byte led, byte pos, byte distance)}{rainbow(byte led, byte pos, byte distance)}}]{\setlength{\rightskip}{0pt plus 5cm}void rainbow (
\begin{DoxyParamCaption}
\item[{byte}]{led, }
\item[{byte}]{pos, }
\item[{byte}]{distance}
\end{DoxyParamCaption}
)}\hypertarget{rainbow_8h_a80198b192c269a2b71cfa41654a3aafd}{}\label{rainbow_8h_a80198b192c269a2b71cfa41654a3aafd}

Definition at line 90 of file rainbow.\+ino.

\index{rainbow.\+h@{rainbow.\+h}!rainbowmode@{rainbowmode}}
\index{rainbowmode@{rainbowmode}!rainbow.\+h@{rainbow.\+h}}
\subsubsection[{\texorpdfstring{rainbowmode()}{rainbowmode()}}]{\setlength{\rightskip}{0pt plus 5cm}void rainbowmode (
\begin{DoxyParamCaption}
{}
\end{DoxyParamCaption}
)}\hypertarget{rainbow_8h_a51e30a1c423190e50127c6651c991612}{}\label{rainbow_8h_a51e30a1c423190e50127c6651c991612}

Definition at line 21 of file rainbow.\+ino.

\index{rainbow.\+h@{rainbow.\+h}!underbody\+\_\+rb@{underbody\+\_\+rb}}
\index{underbody\+\_\+rb@{underbody\+\_\+rb}!rainbow.\+h@{rainbow.\+h}}
\subsubsection[{\texorpdfstring{underbody\+\_\+rb()}{underbody_rb()}}]{\setlength{\rightskip}{0pt plus 5cm}void underbody\+\_\+rb (
\begin{DoxyParamCaption}
{}
\end{DoxyParamCaption}
)}\hypertarget{rainbow_8h_a3656f41cfe48a0bf63e63099673ac4c4}{}\label{rainbow_8h_a3656f41cfe48a0bf63e63099673ac4c4}

Definition at line 74 of file rainbow.\+ino.

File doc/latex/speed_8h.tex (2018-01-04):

\hypertarget{speed_8h}{}\section{speed.\+h File Reference}
\label{speed_8h}\index{speed.\+h@{speed.\+h}}
{\ttfamily \#include \char`\"{}config.\+h\char`\"{}}\\*
Include dependency graph for speed.\+h\+:\nopagebreak
\begin{figure}[H]
\begin{center}
\leavevmode
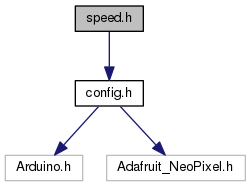
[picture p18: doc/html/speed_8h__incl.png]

\end{center}
\end{figure}
This graph shows which files directly or indirectly include this file\+:\nopagebreak
\begin{figure}[H]
\begin{center}
\leavevmode
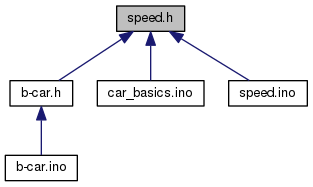
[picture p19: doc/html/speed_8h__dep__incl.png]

\end{center}
\end{figure}
\subsection*{Macros}
\begin{DoxyCompactItemize}
\item 
\#define \hyperlink{speed_8h_adbd34b4269ed16bd87a0d13cb17bdf81}{B\+R\+A\+K\+E\+T\+I\+ME}~1000
\end{DoxyCompactItemize}
\subsection*{Functions}
\begin{DoxyCompactItemize}
\item 
void \hyperlink{speed_8h_ae87a94769934715c309733cfdf2abcb4}{setup\+\_\+interrupt} ()
\item 
unsigned int \hyperlink{speed_8h_afc7b1718f9b23966dfed24056f67996f}{getspeed} ()
\begin{DoxyCompactList}\small\item\em Get current speed. \end{DoxyCompactList}\item 
void \hyperlink{speed_8h_aa41dbc9d264f533090ac3c808c43171f}{acceleration} (unsigned int newspeed)
\begin{DoxyCompactList}\small\item\em Test for negative accelaration (braking) \end{DoxyCompactList}\item 
bool \hyperlink{speed_8h_a3ad56507af5eec4c270def2058efbc3b}{braking} ()
\begin{DoxyCompactList}\small\item\em Braking information. \end{DoxyCompactList}\item 
void \hyperlink{speed_8h_a2004678343c1f7b145dc10aae949a4ec}{resetspeed} ()
\item 
byte \hyperlink{speed_8h_aa1b4f1cc5cf5ba94e3bc38f44e0c7001}{getspeedidx} ()
\end{DoxyCompactItemize}
\subsection*{Variables}
\begin{DoxyCompactItemize}
\item 
static volatile byte \hyperlink{speed_8h_aded4e91dd554c212e6c75ef7148a7845}{speedidx}
\item 
unsigned long \hyperlink{group__speed_ga605bafc427aaa8e9718a112441ba88a7}{speedts}
\item 
unsigned long \hyperlink{speed_8h_a66ce79a1ea6b700d56211c146f679649}{braketime}
\item 
unsigned int \hyperlink{speed_8h_a63232e097931bc02aa65b3b7dadbb74b}{curspeed}
\item 
bool \hyperlink{speed_8h_ad13fd9ed7295daa9a51dd2fade080e50}{isbraking}
\end{DoxyCompactItemize}

\subsection{Macro Definition Documentation}
\index{speed.\+h@{speed.\+h}!B\+R\+A\+K\+E\+T\+I\+ME@{B\+R\+A\+K\+E\+T\+I\+ME}}
\index{B\+R\+A\+K\+E\+T\+I\+ME@{B\+R\+A\+K\+E\+T\+I\+ME}!speed.\+h@{speed.\+h}}
\subsubsection[{\texorpdfstring{B\+R\+A\+K\+E\+T\+I\+ME}{BRAKETIME}}]{\setlength{\rightskip}{0pt plus 5cm}\#define B\+R\+A\+K\+E\+T\+I\+ME~1000}\hypertarget{speed_8h_adbd34b4269ed16bd87a0d13cb17bdf81}{}\label{speed_8h_adbd34b4269ed16bd87a0d13cb17bdf81}

Definition at line 8 of file speed.\+h.

\subsection{Function Documentation}
\index{speed.\+h@{speed.\+h}!acceleration@{acceleration}}
\index{acceleration@{acceleration}!speed.\+h@{speed.\+h}}
\subsubsection[{\texorpdfstring{acceleration(unsigned int newspeed)}{acceleration(unsigned int newspeed)}}]{\setlength{\rightskip}{0pt plus 5cm}void acceleration (
\begin{DoxyParamCaption}
\item[{unsigned int}]{newspeed}
\end{DoxyParamCaption}
)}\hypertarget{speed_8h_aa41dbc9d264f533090ac3c808c43171f}{}\label{speed_8h_aa41dbc9d264f533090ac3c808c43171f}

Test for negative accelaration (braking) 

\begin{DoxyParams}{Parameters}
{\em newspeed} & current speed. \\
\hline
\end{DoxyParams}

Definition at line 96 of file speed.\+ino.

\index{speed.\+h@{speed.\+h}!braking@{braking}}
\index{braking@{braking}!speed.\+h@{speed.\+h}}
\subsubsection[{\texorpdfstring{braking()}{braking()}}]{\setlength{\rightskip}{0pt plus 5cm}bool braking (
\begin{DoxyParamCaption}
{}
\end{DoxyParamCaption}
)}\hypertarget{speed_8h_a3ad56507af5eec4c270def2058efbc3b}{}\label{speed_8h_a3ad56507af5eec4c270def2058efbc3b}

Braking information. 

Return true if car is braking. \begin{DoxyReturn}{Returns}
braking state. 
\end{DoxyReturn}

Definition at line 116 of file speed.\+ino.

\index{speed.\+h@{speed.\+h}!getspeed@{getspeed}}
\index{getspeed@{getspeed}!speed.\+h@{speed.\+h}}
\subsubsection[{\texorpdfstring{getspeed()}{getspeed()}}]{\setlength{\rightskip}{0pt plus 5cm}unsigned int getspeed (
\begin{DoxyParamCaption}
{}
\end{DoxyParamCaption}
)}\hypertarget{speed_8h_afc7b1718f9b23966dfed24056f67996f}{}\label{speed_8h_afc7b1718f9b23966dfed24056f67996f}

Get current speed. 

The speed is measured as integral of interrupts in an interval of at least 256ms. The smallest measurable speed is one interrupt per 256ms. This function returns an unsigned integer, so the smallest value above 0 should be 1. To get this result the count of interrupts is bit shifted by 8.

1$<$$<$8 = 256; 256/256 = 1

But what does 1 represent?

I put 16 interrupt marks to tire of my Bobby Car. One interrupt every 250 ms are 15 rpm (revolutions per minute).

My Bobby Car has a tire diameter of about 153 mm. So the circumference is 478mm (d$\ast$pi).

478mm $\ast$ 15 rpm = 0.\+4302 km/h

\begin{DoxyReturn}{Returns}
current speed. 
\end{DoxyReturn}
\begin{DoxySeeAlso}{See also}
\hyperlink{group__speed_ga44395845abd4a9c31e4fbe88ed717fa3}{I\+S\+R(\+P\+C\+I\+N\+T\+\_\+\+V\+E\+C\+T\+O\+R)} 

\hyperlink{car__basics_8h_ac7295d1018b2b948084ba5dbacf09d74}{tacho()} 
\end{DoxySeeAlso}

Definition at line 70 of file speed.\+ino.

\index{speed.\+h@{speed.\+h}!getspeedidx@{getspeedidx}}
\index{getspeedidx@{getspeedidx}!speed.\+h@{speed.\+h}}
\subsubsection[{\texorpdfstring{getspeedidx()}{getspeedidx()}}]{\setlength{\rightskip}{0pt plus 5cm}byte getspeedidx (
\begin{DoxyParamCaption}
{}
\end{DoxyParamCaption}
)}\hypertarget{speed_8h_aa1b4f1cc5cf5ba94e3bc38f44e0c7001}{}\label{speed_8h_aa1b4f1cc5cf5ba94e3bc38f44e0c7001}

Definition at line 129 of file speed.\+ino.

\index{speed.\+h@{speed.\+h}!resetspeed@{resetspeed}}
\index{resetspeed@{resetspeed}!speed.\+h@{speed.\+h}}
\subsubsection[{\texorpdfstring{resetspeed()}{resetspeed()}}]{\setlength{\rightskip}{0pt plus 5cm}void resetspeed (
\begin{DoxyParamCaption}
{}
\end{DoxyParamCaption}
)}\hypertarget{speed_8h_a2004678343c1f7b145dc10aae949a4ec}{}\label{speed_8h_a2004678343c1f7b145dc10aae949a4ec}

Definition at line 121 of file speed.\+ino.

\index{speed.\+h@{speed.\+h}!setup\+\_\+interrupt@{setup\+\_\+interrupt}}
\index{setup\+\_\+interrupt@{setup\+\_\+interrupt}!speed.\+h@{speed.\+h}}
\subsubsection[{\texorpdfstring{setup\+\_\+interrupt()}{setup_interrupt()}}]{\setlength{\rightskip}{0pt plus 5cm}void setup\+\_\+interrupt (
\begin{DoxyParamCaption}
{}
\end{DoxyParamCaption}
)}\hypertarget{speed_8h_ae87a94769934715c309733cfdf2abcb4}{}\label{speed_8h_ae87a94769934715c309733cfdf2abcb4}

Definition at line 19 of file speed.\+ino.

\subsection{Variable Documentation}
\index{speed.\+h@{speed.\+h}!braketime@{braketime}}
\index{braketime@{braketime}!speed.\+h@{speed.\+h}}
\subsubsection[{\texorpdfstring{braketime}{braketime}}]{\setlength{\rightskip}{0pt plus 5cm}unsigned long braketime}\hypertarget{speed_8h_a66ce79a1ea6b700d56211c146f679649}{}\label{speed_8h_a66ce79a1ea6b700d56211c146f679649}

Definition at line 15 of file speed.\+ino.

\index{speed.\+h@{speed.\+h}!curspeed@{curspeed}}
\index{curspeed@{curspeed}!speed.\+h@{speed.\+h}}
\subsubsection[{\texorpdfstring{curspeed}{curspeed}}]{\setlength{\rightskip}{0pt plus 5cm}unsigned int curspeed}\hypertarget{speed_8h_a63232e097931bc02aa65b3b7dadbb74b}{}\label{speed_8h_a63232e097931bc02aa65b3b7dadbb74b}

Definition at line 16 of file speed.\+ino.

\index{speed.\+h@{speed.\+h}!isbraking@{isbraking}}
\index{isbraking@{isbraking}!speed.\+h@{speed.\+h}}
\subsubsection[{\texorpdfstring{isbraking}{isbraking}}]{\setlength{\rightskip}{0pt plus 5cm}bool isbraking}\hypertarget{speed_8h_ad13fd9ed7295daa9a51dd2fade080e50}{}\label{speed_8h_ad13fd9ed7295daa9a51dd2fade080e50}

Definition at line 17 of file speed.\+ino.

\index{speed.\+h@{speed.\+h}!speedidx@{speedidx}}
\index{speedidx@{speedidx}!speed.\+h@{speed.\+h}}
\subsubsection[{\texorpdfstring{speedidx}{speedidx}}]{\setlength{\rightskip}{0pt plus 5cm}volatile byte speedidx\hspace{0.3cm}{\ttfamily [static]}}\hypertarget{speed_8h_aded4e91dd554c212e6c75ef7148a7845}{}\label{speed_8h_aded4e91dd554c212e6c75ef7148a7845}

Definition at line 9 of file speed.\+h.

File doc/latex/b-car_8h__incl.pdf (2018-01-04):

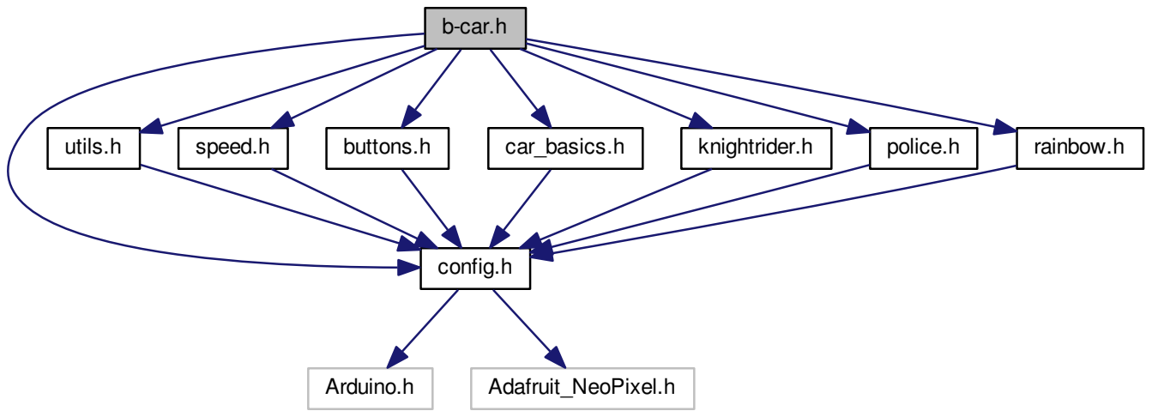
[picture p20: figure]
b-car.h; config.h; utils.h; speed.h; buttons.h; car_basics.h; knightrider.h; police.h; rainbow.h; Arduino.h; Adafruit_NeoPixel.h

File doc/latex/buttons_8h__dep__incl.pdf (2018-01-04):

buttons.h

b-car.h buttons.ino

b-car.ino

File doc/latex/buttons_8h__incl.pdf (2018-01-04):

buttons.h

config.h

Arduino.h Adafruit_NeoPixel.h

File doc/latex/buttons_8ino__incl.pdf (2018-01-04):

buttons.ino

buttons.h

config.h

Arduino.h Adafruit_NeoPixel.h

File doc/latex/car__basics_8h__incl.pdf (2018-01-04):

car_basics.h

config.h

Arduino.h Adafruit_NeoPixel.h

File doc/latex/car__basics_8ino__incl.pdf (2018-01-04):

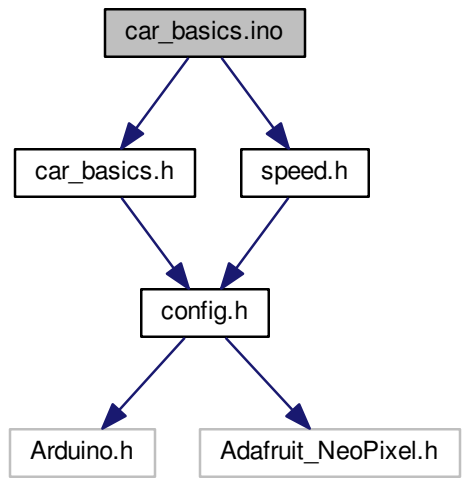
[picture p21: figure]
car_basics.ino; car_basics.h; speed.h; config.h; Arduino.h; Adafruit_NeoPixel.h

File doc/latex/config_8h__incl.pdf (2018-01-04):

config.h

Arduino.h Adafruit_NeoPixel.h

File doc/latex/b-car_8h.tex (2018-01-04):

\hypertarget{b-car_8h}{}\section{b-\/car.h File Reference}
\label{b-car_8h}\index{b-\/car.\+h@{b-\/car.\+h}}
{\ttfamily \#include \char`\"{}config.\+h\char`\"{}}\\*
{\ttfamily \#include \char`\"{}utils.\+h\char`\"{}}\\*
{\ttfamily \#include \char`\"{}speed.\+h\char`\"{}}\\*
{\ttfamily \#include \char`\"{}buttons.\+h\char`\"{}}\\*
{\ttfamily \#include \char`\"{}car\+\_\+basics.\+h\char`\"{}}\\*
{\ttfamily \#include \char`\"{}knightrider.\+h\char`\"{}}\\*
{\ttfamily \#include \char`\"{}police.\+h\char`\"{}}\\*
{\ttfamily \#include \char`\"{}rainbow.\+h\char`\"{}}\\*
Include dependency graph for b-\/car.h\+:\nopagebreak
\begin{figure}[H]
\begin{center}
\leavevmode
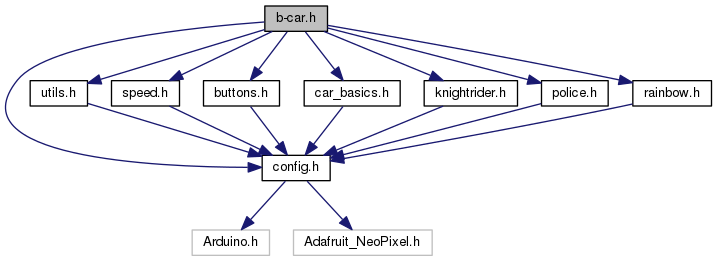
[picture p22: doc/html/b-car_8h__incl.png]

\end{center}
\end{figure}
This graph shows which files directly or indirectly include this file\+:\nopagebreak
\begin{figure}[H]
\begin{center}
\leavevmode

\end{center}
\end{figure}
\subsection*{Functions}
\begin{DoxyCompactItemize}
\item 
void \hyperlink{group__car_gaa0a39b0689218537e29a29f9c3f2af47}{normalmode} ()
\begin{DoxyCompactList}\small\item\em Normal operation mode. \end{DoxyCompactList}\end{DoxyCompactItemize}

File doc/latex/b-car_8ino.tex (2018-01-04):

\hypertarget{b-car_8ino}{}\section{b-\/car.ino File Reference}
\label{b-car_8ino}\index{b-\/car.\+ino@{b-\/car.\+ino}}

Main file.  

{\ttfamily \#include $<$Adafruit\+\_\+\+Neo\+Pixel.\+h$>$}\\*
{\ttfamily \#include \char`\"{}b-\/car.\+h\char`\"{}}\\*
Include dependency graph for b-\/car.ino\+:\nopagebreak
\begin{figure}[H]
\begin{center}
\leavevmode
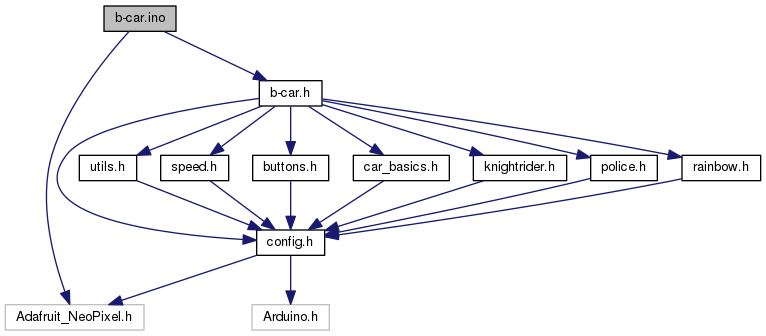
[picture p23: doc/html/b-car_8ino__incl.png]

\end{center}
\end{figure}
\subsection*{Functions}
\begin{DoxyCompactItemize}
\item 
void \hyperlink{group__car_gaa0a39b0689218537e29a29f9c3f2af47}{normalmode} ()
\begin{DoxyCompactList}\small\item\em Normal operation mode. \end{DoxyCompactList}\end{DoxyCompactItemize}
\begin{DoxyCompactItemize}
\item 
Adafruit\+\_\+\+Neo\+Pixel \hyperlink{group__main_gacf2771bd8bfaf855bbcc6c30301bf380}{strip} = Adafruit\+\_\+\+Neo\+Pixel(\hyperlink{group__deployment_ga4c4ae9a4146ce8d6a5debc90300d9abd}{N\+U\+M\+\_\+\+L\+E\+DS}, \hyperlink{group__deployment_gae1a27401b7fb01ccb9a82dbddbb54eea}{P\+IN}, N\+E\+O\+\_\+\+R\+GB + N\+E\+O\+\_\+\+K\+H\+Z800)
\item 
byte \hyperlink{group__main_ga988166baebc4b27bd18de27cd40f8b5a}{mode} = 0
\begin{DoxyCompactList}\small\item\em stores current operation mode \end{DoxyCompactList}\item 
volatile unsigned long \hyperlink{group__main_ga4f944bfefd58754546ebcc7c5143442c}{time}
\begin{DoxyCompactList}\small\item\em Global accessible variable that stores the current time after program start in ms. \end{DoxyCompactList}\item 
void \hyperlink{group__main_ga4fc01d736fe50cf5b977f755b675f11d}{setup} ()
\begin{DoxyCompactList}\small\item\em Initial setup. \end{DoxyCompactList}\item 
void \hyperlink{group__main_gafe461d27b9c48d5921c00d521181f12f}{loop} ()
\begin{DoxyCompactList}\small\item\em Main loop. \end{DoxyCompactList}\end{DoxyCompactItemize}

\subsection{Detailed Description}
Main file. 

\begin{DoxyAuthor}{Author}
copyrights 
\end{DoxyAuthor}

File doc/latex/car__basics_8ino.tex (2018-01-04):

\hypertarget{car__basics_8ino}{}\section{car\+\_\+basics.\+ino File Reference}
\label{car__basics_8ino}\index{car\+\_\+basics.\+ino@{car\+\_\+basics.\+ino}}

Basic car functionality.  

{\ttfamily \#include \char`\"{}car\+\_\+basics.\+h\char`\"{}}\\*
{\ttfamily \#include \char`\"{}speed.\+h\char`\"{}}\\*
Include dependency graph for car\+\_\+basics.\+ino\+:\nopagebreak
\begin{figure}[H]
\begin{center}
\leavevmode
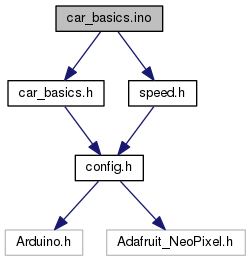
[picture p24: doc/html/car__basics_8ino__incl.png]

\end{center}
\end{figure}
\begin{DoxyCompactItemize}
\item 
const byte \hyperlink{group__car_gac03fd0ab9cbcc53730039ad03e9b094d}{turn\+\_\+light\+\_\+left} \mbox{[}$\,$\mbox{]} =\{17,27\}
\item 
const byte \hyperlink{group__car_ga1a25903a2850d9849775664473070489}{low\+\_\+beam\+\_\+row} \mbox{[}$\,$\mbox{]} =\{1,2,16,15\}
\item 
const byte \hyperlink{group__car_ga1ecea646e1c5dcdfc643287a5f2041bb}{high\+\_\+beam\+\_\+row} \mbox{[}$\,$\mbox{]} = \{1,2,16,15\}
\item 
const byte \hyperlink{group__car_ga5009aa0cbe6b32a72b085489b027800e}{front\+\_\+row} \mbox{[}$\,$\mbox{]} = \{3,4,5,13,14\}
\item 
const byte \hyperlink{group__car_ga6ade605406f4c1ce9f03a5a2530f6dbe}{tacho\+\_\+row} \mbox{[}$\,$\mbox{]} = \{12,11,10,9,8,7,6\}
\item 
const byte \hyperlink{group__car_gaa5a6ee27fdf1d7c939cdf2a7266d7e84}{turn\+\_\+light\+\_\+right} \mbox{[}$\,$\mbox{]} =\{0,30\}
\item 
const byte \hyperlink{group__car_gaac36c9836edd3a125668213f0fb72b5a}{down\+\_\+left\+\_\+row} \mbox{[}$\,$\mbox{]} = \{18,19,20,21\}
\item 
const byte \hyperlink{group__car_gadbf10ff9ee353128c568e07c32b1ffa9}{down\+\_\+right\+\_\+row} \mbox{[}$\,$\mbox{]} = \{22,23,24,25\}
\item 
const byte \hyperlink{group__car_ga516415cfaebc59b71f822fb4cf86b22c}{back\+\_\+light\+\_\+row} \mbox{[}$\,$\mbox{]} = \{26,28,29,31\}
\item 
void \hyperlink{group__car_gaca3b725ebee32d3719a9c02b41002ea3}{turn\+\_\+right} ()
\begin{DoxyCompactList}\small\item\em Activate right turn lights. \end{DoxyCompactList}\item 
void \hyperlink{group__car_ga0565ad7a822d9d334bb50c088af22361}{turn\+\_\+left} ()
\begin{DoxyCompactList}\small\item\em Activate left turn lights. \end{DoxyCompactList}\item 
void \hyperlink{group__car_ga6b1fd674445dd1c654dfe8b8b65f168e}{beam} (unsigned long state)
\begin{DoxyCompactList}\small\item\em Activate low beam or high beam. \end{DoxyCompactList}\item 
void \hyperlink{group__car_ga29d5eff542aae0196b8e84b8a752e1df}{low\+\_\+beam} (bool on)
\item 
void \hyperlink{group__car_ga1088d06b4ab015d579e0ac2510d39f25}{high\+\_\+beam} (bool on)
\item 
void \hyperlink{group__car_gac7295d1018b2b948084ba5dbacf09d74}{tacho} ()
\begin{DoxyCompactList}\small\item\em Display the current speed on tacho\+\_\+row L\+E\+Ds. \end{DoxyCompactList}\item 
void \hyperlink{group__car_gaffb7c011f82f3fb47b39ebb2713a1cd8}{flash} ()
\begin{DoxyCompactList}\small\item\em Flash light. \end{DoxyCompactList}\item 
void \hyperlink{group__car_ga1ac48972153097ad7a16fffc032fc5f1}{brakelight} ()
\begin{DoxyCompactList}\small\item\em Brake light. \end{DoxyCompactList}\end{DoxyCompactItemize}

\subsection{Detailed Description}
Basic car functionality. 

\begin{DoxyAuthor}{Author}
copyrights 
\end{DoxyAuthor}
\begin{DoxyRefDesc}{Todo}
\item[\hyperlink{todo__todo000001}{Todo}]Write a function for brake lights. \end{DoxyRefDesc}

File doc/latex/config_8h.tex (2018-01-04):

\hypertarget{config_8h}{}\section{config.\+h File Reference}
\label{config_8h}\index{config.\+h@{config.\+h}}

Adjust your settings here.  

{\ttfamily \#include $<$Arduino.\+h$>$}\\*
{\ttfamily \#include $<$Adafruit\+\_\+\+Neo\+Pixel.\+h$>$}\\*
Include dependency graph for config.\+h\+:\nopagebreak
\begin{figure}[H]
\begin{center}
\leavevmode

\end{center}
\end{figure}
This graph shows which files directly or indirectly include this file\+:\nopagebreak
\begin{figure}[H]
\begin{center}
\leavevmode
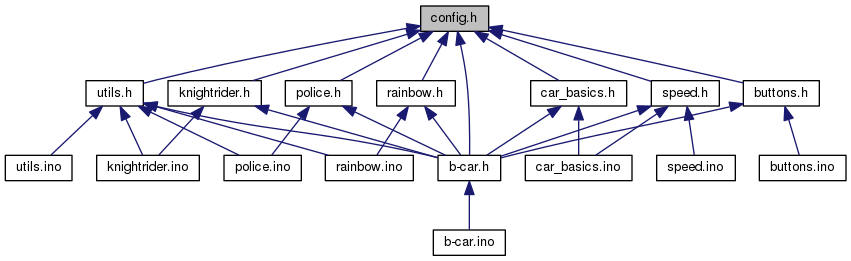
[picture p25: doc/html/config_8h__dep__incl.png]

\end{center}
\end{figure}
\subsection*{Macros}
\begin{DoxyCompactItemize}
\item 
\#define \hyperlink{group__buttons_gab47d09cf51ee6fbdc1b7b255f57ec896}{B\+U\+T\+T\+O\+N\+S1}~A1
\begin{DoxyCompactList}\small\item\em Define analog input for first five buttons. \end{DoxyCompactList}\item 
\#define \hyperlink{group__buttons_gac3f0a90f8f8169f919f346be1ea485db}{B\+U\+T\+T\+O\+N\+S2}~A2
\begin{DoxyCompactList}\small\item\em Define analog input for second five buttons. \end{DoxyCompactList}\item 
\#define \hyperlink{group__buttons_ga171ef18ea7b584f85234640a918da857}{D\+E\+B\+O\+U\+N\+CE}~20
\begin{DoxyCompactList}\small\item\em Define delay in ms to debounce button presses. \end{DoxyCompactList}\item 
\#define \hyperlink{group__buttons_ga0dae655e00097db2f5737cef9f1fe1e6}{S5}~0b0000000001
\begin{DoxyCompactList}\small\item\em Bit mask for button 5. \end{DoxyCompactList}\item 
\#define \hyperlink{group__buttons_gac6dd50ea82e237280daf26bd9b562ba9}{S4}~0b0000000010
\begin{DoxyCompactList}\small\item\em Bit mask for button 4. \end{DoxyCompactList}\item 
\#define \hyperlink{group__buttons_gab29872af8ce9dc9463b7f7ecfbea02ae}{S3}~0b0000000100
\begin{DoxyCompactList}\small\item\em Bit mask for button 3. \end{DoxyCompactList}\item 
\#define \hyperlink{group__buttons_gad5e70dee3c36d645b0eb1743b8a7d2bf}{S2}~0b0000001000
\begin{DoxyCompactList}\small\item\em Bit mask for button 2. \end{DoxyCompactList}\item 
\#define \hyperlink{group__buttons_ga690d30e9ad3647835c243368b36d4c41}{S1}~0b0000010000
\begin{DoxyCompactList}\small\item\em Bit mask for button 1. \end{DoxyCompactList}\item 
\#define \hyperlink{group__buttons_ga1ff88b4fe56e1c80a371b1fbda4e4e74}{S10}~0b0000100000
\begin{DoxyCompactList}\small\item\em Bit mask for button 10. \end{DoxyCompactList}\item 
\#define \hyperlink{group__buttons_ga6eef6bdffd8bac54d6b4be0176dd20ff}{S9}~0b0001000000
\begin{DoxyCompactList}\small\item\em Bit mask for button 9. \end{DoxyCompactList}\item 
\#define \hyperlink{group__buttons_ga4516955061f24ae7162de20aff005c9b}{S8}~0b0010000000
\begin{DoxyCompactList}\small\item\em Bit mask for button 8. \end{DoxyCompactList}\item 
\#define \hyperlink{group__buttons_ga6580eeddd36d0d97cdde6f6a4695ed12}{S7}~0b0100000000
\begin{DoxyCompactList}\small\item\em Bit mask for button 7. \end{DoxyCompactList}\item 
\#define \hyperlink{group__buttons_gab86bfbee3d71830e88c61a3f8d5aebf4}{S6}~0b1000000000
\begin{DoxyCompactList}\small\item\em Bit mask for button 6. \end{DoxyCompactList}\item 
\#define \hyperlink{group__buttons_ga77a6549a849f9a9472a367e4148289b7}{T\+O\+G\+G\+L\+E\+M\+A\+SK}~0b1110000000
\begin{DoxyCompactList}\small\item\em Bit mask for simulated toggle buttons. \end{DoxyCompactList}\item 
\#define \hyperlink{group__car_ga6670c8646da7675376960bb5773199fd}{T\+U\+R\+N\+L\+I\+G\+HT}~0xffc000
\begin{DoxyCompactList}\small\item\em Color of turn lights. \end{DoxyCompactList}\item 
\#define \hyperlink{group__car_ga61bb8d5dab460079c1b621b2d8a4bd9c}{L\+O\+W\+B\+E\+AM}~0x3f3f3f
\begin{DoxyCompactList}\small\item\em Color of low beam. \end{DoxyCompactList}\item 
\#define \hyperlink{group__car_ga3f561f12573270e4b5329bc5930ad20f}{H\+I\+G\+H\+B\+E\+AM}~0x7f7f7f
\begin{DoxyCompactList}\small\item\em Color of high beam. \end{DoxyCompactList}\item 
\#define \hyperlink{group__car_gae97ccf06dd29b2a0500f378068b678e2}{B\+A\+C\+K\+L\+I\+G\+HT}~0x3f0000
\begin{DoxyCompactList}\small\item\em Color of back lights. \end{DoxyCompactList}\item 
\#define \hyperlink{group__car_ga95743a8e9ccb3be5a627dd9322806751}{B\+R\+A\+K\+E\+L\+I\+G\+HT}~0xff0000
\begin{DoxyCompactList}\small\item\em Color of brake lights. \end{DoxyCompactList}\item 
\#define \hyperlink{group__car_gadbd34b4269ed16bd87a0d13cb17bdf81}{B\+R\+A\+K\+E\+T\+I\+ME}~1000
\begin{DoxyCompactList}\small\item\em time brake lights glow in ms. \end{DoxyCompactList}\item 
\#define \hyperlink{group__knightrider_ga5d96b8b7a94cd393a11cca853832350f}{K\+RR}~0x7f
\begin{DoxyCompactList}\small\item\em Red part of Knight Rider like front row. \end{DoxyCompactList}\item 
\#define \hyperlink{group__knightrider_ga47a5cb8daecea854270c0d09c3ebc24c}{K\+RG}~0x00
\begin{DoxyCompactList}\small\item\em Green part of Knight Rider like front row. \end{DoxyCompactList}\item 
\#define \hyperlink{group__knightrider_gaa315fefb5665924b7d512104bc3965cd}{K\+RB}~0x00
\begin{DoxyCompactList}\small\item\em Blue part of Knight Rider like front row. \end{DoxyCompactList}\item 
\#define \hyperlink{group__knightrider_gadb436e031abc2aed3e3cbbf9078667bb}{K\+R\+P\+E\+R\+I\+OD}~500
\begin{DoxyCompactList}\small\item\em Period in ms the Knight Rider like front row needs to move in one direction. \end{DoxyCompactList}\item 
\#define \hyperlink{group__knightrider_ga64a0c208656bb11ad944489886089b7e}{K\+R\+D\+TZ}~200
\begin{DoxyCompactList}\small\item\em Fade out period in ms for a smooth light flow. \end{DoxyCompactList}\item 
\#define \hyperlink{group__police_ga088f4c3612d1ab1c9f6f139234ae533b}{PR}~0x00
\begin{DoxyCompactList}\small\item\em Red part of the police beacon light. \end{DoxyCompactList}\item 
\#define \hyperlink{group__police_ga037f1be1c3e45bf4d0d4f5ddc159ff30}{PG}~0x00
\begin{DoxyCompactList}\small\item\em Green part of the police beacon light. \end{DoxyCompactList}\item 
\#define \hyperlink{group__police_ga2a06f3773d46878dc58f8dadd6fd0d72}{PB}~0xff
\begin{DoxyCompactList}\small\item\em Blue part of the police beacon light. \end{DoxyCompactList}\item 
\#define \hyperlink{group__police_gaa5b3f73b18472f543c080194bf9c2e79}{P\+P\+E\+R\+I\+OD}~1000
\begin{DoxyCompactList}\small\item\em Rotation period in ms of the police beacon light. \end{DoxyCompactList}\item 
\#define \hyperlink{group__police_ga2b9a2b71c1aa4f1c059461e2db7edf44}{P\+D\+TZ}~200
\begin{DoxyCompactList}\small\item\em Fade out period in ms for a smooth light flow. \end{DoxyCompactList}\item 
\#define \hyperlink{group__police_ga6204e236d3e4ef0beb5b6fd976fecf43}{P\+L\+F\+L\+A\+SH}~0xff0000
\begin{DoxyCompactList}\small\item\em Left side flash color of the police front row. \end{DoxyCompactList}\item 
\#define \hyperlink{group__police_ga98673c164f8917ff7af0016ba30e7ca8}{P\+L\+L\+OW}~0x1f0000
\begin{DoxyCompactList}\small\item\em Left side low light color of the police front row. \end{DoxyCompactList}\item 
\#define \hyperlink{group__police_gac9d0142b6f8cc7735af13e6b91503b97}{P\+R\+F\+L\+A\+SH}~0x0000ff
\begin{DoxyCompactList}\small\item\em Right side flash color of the police front row. \end{DoxyCompactList}\item 
\#define \hyperlink{group__police_gaf4a707e896c2e6df7a0215e4100d75aa}{P\+R\+L\+OW}~0x00001f
\begin{DoxyCompactList}\small\item\em Right side low light color of the police front row. \end{DoxyCompactList}\item 
\#define \hyperlink{group__rainbow_ga36ae3bd3da884ff03d7306f674f70dea}{R\+B\+S\+T\+EP}~40
\begin{DoxyCompactList}\small\item\em Rainbow step size between two L\+E\+Ds. \end{DoxyCompactList}\item 
\#define \hyperlink{group__speed_ga984097794e94beb18c01b6fcbd8f399d}{I\+N\+T\+E\+R\+R\+U\+P\+T\+P\+IN}~P\+C\+I\+N\+T1
\begin{DoxyCompactList}\small\item\em This is P\+B1 per the schematic. \end{DoxyCompactList}\item 
\#define \hyperlink{group__speed_ga77b45027297b1ff40b5b1249afb852e5}{P\+C\+I\+N\+T\+\_\+\+V\+E\+C\+T\+OR}~P\+C\+I\+N\+T0\+\_\+vect
\item 
\#define \hyperlink{group__speed_ga9142f4c677315955ad0ac6266b615d2c}{D\+A\+T\+A\+D\+I\+R\+E\+C\+T\+I\+O\+N\+P\+IN}~D\+D\+B1
\item 
\#define \hyperlink{group__speed_gaab113cddfa5f8856918dcb65238882ca}{P\+O\+R\+T\+P\+IN}~P\+B1
\item 
\#define \hyperlink{group__speed_ga93a1139e66a97ca289f0f1a73903be06}{R\+E\+A\+D\+P\+IN}~P\+I\+N\+B1
\item 
\#define \hyperlink{group__deployment_gae1a27401b7fb01ccb9a82dbddbb54eea}{P\+IN}~0
\item 
\#define \hyperlink{group__deployment_ga4c4ae9a4146ce8d6a5debc90300d9abd}{N\+U\+M\+\_\+\+L\+E\+DS}~32
\end{DoxyCompactItemize}
\subsection*{Variables}
\begin{DoxyCompactItemize}
\item 
const byte \hyperlink{group__deployment_gaa66783b35924c2be3ec318934f0d479f}{turn\+\_\+light\+\_\+left} \mbox{[}2\mbox{]}
\item 
const byte \hyperlink{group__deployment_ga89eb753b2bc73cbce90666cfe4331634}{low\+\_\+beam\+\_\+row} \mbox{[}4\mbox{]}
\item 
const byte \hyperlink{group__deployment_ga8b165874b487053cb404215a7f42e33e}{high\+\_\+beam\+\_\+row} \mbox{[}4\mbox{]}
\item 
const byte \hyperlink{group__deployment_ga848556a6e145736d917b4f0a67ee60ae}{front\+\_\+row} \mbox{[}5\mbox{]}
\item 
const byte \hyperlink{group__deployment_gae646a1734cc95ba36b0998697da68878}{tacho\+\_\+row} \mbox{[}7\mbox{]}
\item 
const byte \hyperlink{group__deployment_ga2c04f83f019c3bf8feeaae688dbbc164}{turn\+\_\+light\+\_\+right} \mbox{[}2\mbox{]}
\item 
const byte \hyperlink{group__deployment_gac8900a0d9fa4f35f99c82be1db05199d}{down\+\_\+left\+\_\+row} \mbox{[}4\mbox{]}
\item 
const byte \hyperlink{group__deployment_gac32ac62cf68805d76bf34bdd3c83fb0c}{down\+\_\+right\+\_\+row} \mbox{[}4\mbox{]}
\item 
const byte \hyperlink{group__deployment_ga3a2101866267bf0af2559a241cdb7cc6}{back\+\_\+light\+\_\+row} \mbox{[}4\mbox{]}
\item 
const byte \hyperlink{group__deployment_ga61c28c043183f54a51db2a5175940b86}{rainbowrow\+\_\+left} \mbox{[}17\mbox{]}
\item 
const byte \hyperlink{group__deployment_gaa16b875157c2f58794ae5136b851c078}{rainbowrow\+\_\+right} \mbox{[}17\mbox{]}
\item 
Adafruit\+\_\+\+Neo\+Pixel \hyperlink{group__deployment_gacf2771bd8bfaf855bbcc6c30301bf380}{strip}
\item 
volatile unsigned long \hyperlink{group__main_ga4f944bfefd58754546ebcc7c5143442c}{time}
\begin{DoxyCompactList}\small\item\em Global accessible variable that stores the current time after program start in ms. \end{DoxyCompactList}\item 
byte \hyperlink{group__main_ga988166baebc4b27bd18de27cd40f8b5a}{mode}
\begin{DoxyCompactList}\small\item\em stores current operation mode \end{DoxyCompactList}\end{DoxyCompactItemize}

\subsection{Detailed Description}
Adjust your settings here. 

Create a custom.\+h file and copy line 15 to second last line of \hyperlink{config_8h}{config.\+h} to it. Then uncomment line 10 of \hyperlink{config_8h}{config.\+h} file. \begin{DoxyAuthor}{Author}
copyrights 
\end{DoxyAuthor}

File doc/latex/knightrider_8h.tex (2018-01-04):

\hypertarget{knightrider_8h}{}\section{knightrider.\+h File Reference}
\label{knightrider_8h}\index{knightrider.\+h@{knightrider.\+h}}
{\ttfamily \#include \char`\"{}config.\+h\char`\"{}}\\*
Include dependency graph for knightrider.\+h\+:\nopagebreak
\begin{figure}[H]
\begin{center}
\leavevmode
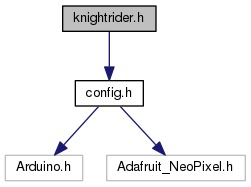
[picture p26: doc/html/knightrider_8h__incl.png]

\end{center}
\end{figure}
This graph shows which files directly or indirectly include this file\+:\nopagebreak
\begin{figure}[H]
\begin{center}
\leavevmode
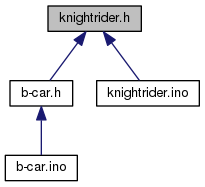
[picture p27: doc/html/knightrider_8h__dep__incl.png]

\end{center}
\end{figure}
\subsection*{Functions}
\begin{DoxyCompactItemize}
\item 
void \hyperlink{group__knightrider_ga58bfb7b9f8fcf7a4b02700359057a6f4}{knightrider} ()
\begin{DoxyCompactList}\small\item\em Knight Rider like front row. \end{DoxyCompactList}\end{DoxyCompactItemize}

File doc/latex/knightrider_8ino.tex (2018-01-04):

\hypertarget{knightrider_8ino}{}\section{knightrider.\+ino File Reference}
\label{knightrider_8ino}\index{knightrider.\+ino@{knightrider.\+ino}}

Knight Rider like front row.  

{\ttfamily \#include \char`\"{}knightrider.\+h\char`\"{}}\\*
{\ttfamily \#include \char`\"{}utils.\+h\char`\"{}}\\*
Include dependency graph for knightrider.\+ino\+:\nopagebreak
\begin{figure}[H]
\begin{center}
\leavevmode
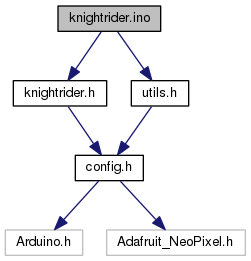
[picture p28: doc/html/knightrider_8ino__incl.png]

\end{center}
\end{figure}
\subsection*{Functions}
{\bf }\par
\begin{DoxyCompactItemize}
\item 
void \hyperlink{group__knightrider_ga58bfb7b9f8fcf7a4b02700359057a6f4}{knightrider} ()
\begin{DoxyCompactList}\small\item\em Knight Rider like front row. \end{DoxyCompactList}\end{DoxyCompactItemize}

\subsection{Detailed Description}
Knight Rider like front row. 

\begin{DoxyAuthor}{Author}
copyrights 
\end{DoxyAuthor}

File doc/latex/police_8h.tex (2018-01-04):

\hypertarget{police_8h}{}\section{police.\+h File Reference}
\label{police_8h}\index{police.\+h@{police.\+h}}
{\ttfamily \#include \char`\"{}config.\+h\char`\"{}}\\*
Include dependency graph for police.\+h\+:\nopagebreak
\begin{figure}[H]
\begin{center}
\leavevmode
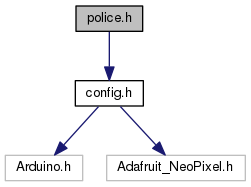
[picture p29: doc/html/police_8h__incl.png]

\end{center}
\end{figure}
This graph shows which files directly or indirectly include this file\+:\nopagebreak
\begin{figure}[H]
\begin{center}
\leavevmode
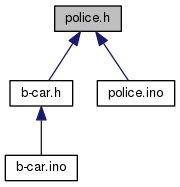
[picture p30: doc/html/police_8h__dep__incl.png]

\end{center}
\end{figure}
\subsection*{Functions}
\begin{DoxyCompactItemize}
\item 
void \hyperlink{group__police_ga55d627c45708bc26866e27d49432eee9}{police} ()
\item 
void \hyperlink{police_8h_a82542db5e1a84d584a1725f36caaf71e}{p\+\_\+front} (boolean ls, boolean rs, boolean left)
\end{DoxyCompactItemize}

\subsection{Function Documentation}
\index{police.\+h@{police.\+h}!p\+\_\+front@{p\+\_\+front}}
\index{p\+\_\+front@{p\+\_\+front}!police.\+h@{police.\+h}}
\subsubsection[{\texorpdfstring{p\+\_\+front(boolean ls, boolean rs, boolean left)}{p_front(boolean ls, boolean rs, boolean left)}}]{\setlength{\rightskip}{0pt plus 5cm}void p\+\_\+front (
\begin{DoxyParamCaption}
\item[{boolean}]{ls, }
\item[{boolean}]{rs, }
\item[{boolean}]{left}
\end{DoxyParamCaption}
)}\hypertarget{police_8h_a82542db5e1a84d584a1725f36caaf71e}{}\label{police_8h_a82542db5e1a84d584a1725f36caaf71e}

Definition at line 80 of file police.\+ino.

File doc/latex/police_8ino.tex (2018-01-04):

\hypertarget{police_8ino}{}\section{police.\+ino File Reference}
\label{police_8ino}\index{police.\+ino@{police.\+ino}}

Police beacon light and front flash.  

{\ttfamily \#include \char`\"{}police.\+h\char`\"{}}\\*
{\ttfamily \#include \char`\"{}utils.\+h\char`\"{}}\\*
Include dependency graph for police.\+ino\+:\nopagebreak
\begin{figure}[H]
\begin{center}
\leavevmode
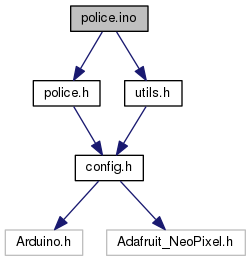
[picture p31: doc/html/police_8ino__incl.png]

\end{center}
\end{figure}
\subsection*{Functions}
{\bf }\par
\begin{DoxyCompactItemize}
\item 
void \hyperlink{group__police_ga55d627c45708bc26866e27d49432eee9}{police} ()
\item 
void \hyperlink{group__police_ga82542db5e1a84d584a1725f36caaf71e}{p\+\_\+front} (boolean ls, boolean rs, boolean left)
\end{DoxyCompactItemize}

\subsection{Detailed Description}
Police beacon light and front flash. 

\begin{DoxyAuthor}{Author}
copyrights 
\end{DoxyAuthor}
\begin{DoxyRefDesc}{Todo}
\item[\hyperlink{todo__todo000003}{Todo}]May add more flasher. 

Extract beacon light as separate function. \end{DoxyRefDesc}

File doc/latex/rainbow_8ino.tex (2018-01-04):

\hypertarget{rainbow_8ino}{}\section{rainbow.\+ino File Reference}
\label{rainbow_8ino}\index{rainbow.\+ino@{rainbow.\+ino}}

Rainbow effect functions.  

{\ttfamily \#include \char`\"{}rainbow.\+h\char`\"{}}\\*
{\ttfamily \#include \char`\"{}utils.\+h\char`\"{}}\\*
Include dependency graph for rainbow.\+ino\+:\nopagebreak
\begin{figure}[H]
\begin{center}
\leavevmode
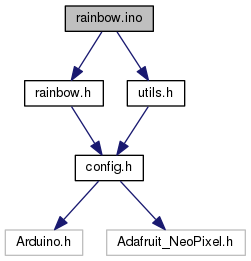
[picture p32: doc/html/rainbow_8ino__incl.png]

\end{center}
\end{figure}
\begin{DoxyCompactItemize}
\item 
const byte \hyperlink{group__rainbow_gad4e8497757364dbc8187298bd87acc44}{rainbowrow\+\_\+left} \mbox{[}$\,$\mbox{]} = \{5,13,14,17,15,16,18,19,20,21,30,31,29, 9,10,11,12\}
\item 
const byte \hyperlink{group__rainbow_ga00c047fede9a8b6c020ba1d108d63cea}{rainbowrow\+\_\+right} \mbox{[}$\,$\mbox{]} = \{5, 4, 3, 0, 2, 1,22,23,24,25,27,26,28, 9, 8, 7, 6\}
\item 
void \hyperlink{group__rainbow_ga51e30a1c423190e50127c6651c991612}{rainbowmode} ()
\item 
void \hyperlink{group__rainbow_ga3656f41cfe48a0bf63e63099673ac4c4}{underbody\+\_\+rb} ()
\item 
void \hyperlink{group__rainbow_ga80198b192c269a2b71cfa41654a3aafd}{rainbow} (byte led, byte pos, byte distance)
\end{DoxyCompactItemize}

\subsection{Detailed Description}
Rainbow effect functions. 

\begin{DoxyAuthor}{Author}
copyrights 
\end{DoxyAuthor}
\begin{DoxyRefDesc}{Todo}
\item[\hyperlink{todo__todo000004}{Todo}]Make period of rainbow cycle configurable in \hyperlink{config_8h}{config.\+h} \end{DoxyRefDesc}

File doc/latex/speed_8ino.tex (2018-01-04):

\hypertarget{speed_8ino}{}\section{speed.\+ino File Reference}
\label{speed_8ino}\index{speed.\+ino@{speed.\+ino}}

Measure speed.  

{\ttfamily \#include \char`\"{}speed.\+h\char`\"{}}\\*
Include dependency graph for speed.\+ino\+:\nopagebreak
\begin{figure}[H]
\begin{center}
\leavevmode
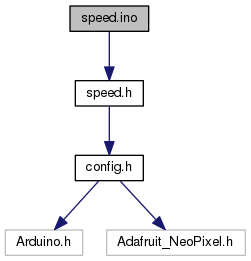
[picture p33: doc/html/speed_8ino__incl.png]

\end{center}
\end{figure}
\begin{DoxyCompactItemize}
\item 
unsigned long \hyperlink{group__speed_ga605bafc427aaa8e9718a112441ba88a7}{speedts}
\item 
unsigned long \hyperlink{group__speed_ga66ce79a1ea6b700d56211c146f679649}{braketime}
\item 
unsigned int \hyperlink{group__speed_ga63232e097931bc02aa65b3b7dadbb74b}{curspeed}
\item 
bool \hyperlink{group__speed_gad13fd9ed7295daa9a51dd2fade080e50}{isbraking}
\item 
void \hyperlink{group__speed_gae87a94769934715c309733cfdf2abcb4}{setup\+\_\+interrupt} ()
\item 
\hyperlink{group__speed_ga44395845abd4a9c31e4fbe88ed717fa3}{I\+SR} (\hyperlink{group__speed_ga77b45027297b1ff40b5b1249afb852e5}{P\+C\+I\+N\+T\+\_\+\+V\+E\+C\+T\+OR})
\item 
unsigned int \hyperlink{group__speed_gafc7b1718f9b23966dfed24056f67996f}{getspeed} ()
\begin{DoxyCompactList}\small\item\em Get current speed. \end{DoxyCompactList}\item 
void \hyperlink{group__speed_gaa41dbc9d264f533090ac3c808c43171f}{acceleration} (unsigned int newspeed)
\begin{DoxyCompactList}\small\item\em Test for negative accelaration (braking) \end{DoxyCompactList}\item 
bool \hyperlink{group__speed_ga3ad56507af5eec4c270def2058efbc3b}{braking} ()
\begin{DoxyCompactList}\small\item\em Braking information. \end{DoxyCompactList}\item 
void \hyperlink{group__speed_ga2004678343c1f7b145dc10aae949a4ec}{resetspeed} ()
\item 
byte \hyperlink{group__speed_gaa1b4f1cc5cf5ba94e3bc38f44e0c7001}{getspeedidx} ()
\end{DoxyCompactItemize}

\subsection{Detailed Description}
Measure speed. 

\begin{DoxyAuthor}{Author}
copyrights 
\end{DoxyAuthor}
\begin{DoxyRefDesc}{Todo}
\item[\hyperlink{todo__todo000005}{Todo}]Write a function that detects braking via negative acceleration. \end{DoxyRefDesc}

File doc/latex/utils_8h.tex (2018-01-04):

\hypertarget{utils_8h}{}\section{utils.\+h File Reference}
\label{utils_8h}\index{utils.\+h@{utils.\+h}}
{\ttfamily \#include \char`\"{}config.\+h\char`\"{}}\\*
Include dependency graph for utils.\+h\+:\nopagebreak
\begin{figure}[H]
\begin{center}
\leavevmode
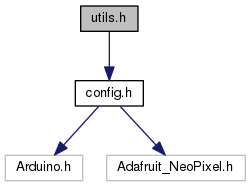
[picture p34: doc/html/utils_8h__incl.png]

\end{center}
\end{figure}
This graph shows which files directly or indirectly include this file\+:\nopagebreak
\begin{figure}[H]
\begin{center}
\leavevmode

\end{center}
\end{figure}
\subsection*{Functions}
\begin{DoxyCompactItemize}
\item 
void \hyperlink{utils_8h_a798729dca95209ecdc609807a653a2bf}{clear\+All} ()
\item 
uint8\+\_\+t \hyperlink{utils_8h_ab5a87ca857f392dbad3bf3a4582c3f0e}{fade8} (uint16\+\_\+t distance, uint16\+\_\+t dtz)
\item 
uint8\+\_\+t \hyperlink{utils_8h_ae7f706e9934c4154b7a4e222f14c8c9a}{percent8} (uint8\+\_\+t full, uint8\+\_\+t fac)
\item 
uint8\+\_\+t \hyperlink{group___fast_l_e_d_ga538b510f61cc75c8e4491f9f2797ee7c}{sin8} (uint8\+\_\+t theta)
\item 
uint8\+\_\+t \hyperlink{group___fast_l_e_d_ga007b62e82ea1556ea7b0e3d2656bce09}{cos8} (uint8\+\_\+t theta)
\item 
uint32\+\_\+t \hyperlink{group___fast_l_e_d_ga953424274959481c9d46b57d249b3722}{Wheel} (byte Wheel\+Pos)
\begin{DoxyCompactList}\small\item\em Input a value 0 to 255 to get a color value. The colours are a transition r -\/ g -\/ b -\/ back to r. \end{DoxyCompactList}\end{DoxyCompactItemize}
\subsection*{Variables}
\begin{DoxyCompactItemize}
\item 
const uint8\+\_\+t \hyperlink{group___fast_l_e_d_gadc654138105ff193df0fbc7a0c21806c}{b\+\_\+m16\+\_\+interleave} \mbox{[}$\,$\mbox{]} = \{ 0, 49, 49, 41, 90, 27, 117, 10 \}
\end{DoxyCompactItemize}

\subsection{Function Documentation}
\index{utils.\+h@{utils.\+h}!clear\+All@{clear\+All}}
\index{clear\+All@{clear\+All}!utils.\+h@{utils.\+h}}
\subsubsection[{\texorpdfstring{clear\+All()}{clearAll()}}]{\setlength{\rightskip}{0pt plus 5cm}void clear\+All (
\begin{DoxyParamCaption}
{}
\end{DoxyParamCaption}
)}\hypertarget{utils_8h_a798729dca95209ecdc609807a653a2bf}{}\label{utils_8h_a798729dca95209ecdc609807a653a2bf}

Definition at line 8 of file utils.\+ino.

\index{utils.\+h@{utils.\+h}!fade8@{fade8}}
\index{fade8@{fade8}!utils.\+h@{utils.\+h}}
\subsubsection[{\texorpdfstring{fade8(uint16\+\_\+t distance, uint16\+\_\+t dtz)}{fade8(uint16_t distance, uint16_t dtz)}}]{\setlength{\rightskip}{0pt plus 5cm}uint8\+\_\+t fade8 (
\begin{DoxyParamCaption}
\item[{uint16\+\_\+t}]{distance, }
\item[{uint16\+\_\+t}]{dtz}
\end{DoxyParamCaption}
)}\hypertarget{utils_8h_ab5a87ca857f392dbad3bf3a4582c3f0e}{}\label{utils_8h_ab5a87ca857f392dbad3bf3a4582c3f0e}

Definition at line 14 of file utils.\+ino.

\index{utils.\+h@{utils.\+h}!percent8@{percent8}}
\index{percent8@{percent8}!utils.\+h@{utils.\+h}}
\subsubsection[{\texorpdfstring{percent8(uint8\+\_\+t full, uint8\+\_\+t fac)}{percent8(uint8_t full, uint8_t fac)}}]{\setlength{\rightskip}{0pt plus 5cm}uint8\+\_\+t percent8 (
\begin{DoxyParamCaption}
\item[{uint8\+\_\+t}]{full, }
\item[{uint8\+\_\+t}]{fac}
\end{DoxyParamCaption}
)}\hypertarget{utils_8h_ae7f706e9934c4154b7a4e222f14c8c9a}{}\label{utils_8h_ae7f706e9934c4154b7a4e222f14c8c9a}

Definition at line 23 of file utils.\+ino.

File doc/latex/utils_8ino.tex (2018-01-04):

\hypertarget{utils_8ino}{}\section{utils.\+ino File Reference}
\label{utils_8ino}\index{utils.\+ino@{utils.\+ino}}

Collection of utils.  

{\ttfamily \#include \char`\"{}utils.\+h\char`\"{}}\\*
Include dependency graph for utils.\+ino\+:\nopagebreak
\begin{figure}[H]
\begin{center}
\leavevmode

\end{center}
\end{figure}
\subsection*{Functions}
\begin{DoxyCompactItemize}
\item 
void \hyperlink{utils_8ino_a798729dca95209ecdc609807a653a2bf}{clear\+All} ()
\item 
uint8\+\_\+t \hyperlink{utils_8ino_ab5a87ca857f392dbad3bf3a4582c3f0e}{fade8} (uint16\+\_\+t distance, uint16\+\_\+t dtz)
\item 
uint8\+\_\+t \hyperlink{utils_8ino_ae7f706e9934c4154b7a4e222f14c8c9a}{percent8} (uint8\+\_\+t full, uint8\+\_\+t fac)
\item 
uint8\+\_\+t \hyperlink{group___fast_l_e_d_ga538b510f61cc75c8e4491f9f2797ee7c}{sin8} (uint8\+\_\+t theta)
\item 
uint8\+\_\+t \hyperlink{group___fast_l_e_d_ga007b62e82ea1556ea7b0e3d2656bce09}{cos8} (uint8\+\_\+t theta)
\item 
uint32\+\_\+t \hyperlink{group___adafruit_ga953424274959481c9d46b57d249b3722}{Wheel} (byte Wheel\+Pos)
\begin{DoxyCompactList}\small\item\em Input a value 0 to 255 to get a color value. The colours are a transition r -\/ g -\/ b -\/ back to r. \end{DoxyCompactList}\end{DoxyCompactItemize}

\subsection{Detailed Description}
Collection of utils. 

\begin{DoxyAuthor}{Author}
copyrights 
\end{DoxyAuthor}

\subsection{Function Documentation}
\index{utils.\+ino@{utils.\+ino}!clear\+All@{clear\+All}}
\index{clear\+All@{clear\+All}!utils.\+ino@{utils.\+ino}}
\subsubsection[{\texorpdfstring{clear\+All()}{clearAll()}}]{\setlength{\rightskip}{0pt plus 5cm}void clear\+All (
\begin{DoxyParamCaption}
{}
\end{DoxyParamCaption}
)}\hypertarget{utils_8ino_a798729dca95209ecdc609807a653a2bf}{}\label{utils_8ino_a798729dca95209ecdc609807a653a2bf}

Definition at line 8 of file utils.\+ino.

\index{utils.\+ino@{utils.\+ino}!fade8@{fade8}}
\index{fade8@{fade8}!utils.\+ino@{utils.\+ino}}
\subsubsection[{\texorpdfstring{fade8(uint16\+\_\+t distance, uint16\+\_\+t dtz)}{fade8(uint16_t distance, uint16_t dtz)}}]{\setlength{\rightskip}{0pt plus 5cm}uint8\+\_\+t fade8 (
\begin{DoxyParamCaption}
\item[{uint16\+\_\+t}]{distance, }
\item[{uint16\+\_\+t}]{dtz}
\end{DoxyParamCaption}
)}\hypertarget{utils_8ino_ab5a87ca857f392dbad3bf3a4582c3f0e}{}\label{utils_8ino_ab5a87ca857f392dbad3bf3a4582c3f0e}

Definition at line 14 of file utils.\+ino.

\index{utils.\+ino@{utils.\+ino}!percent8@{percent8}}
\index{percent8@{percent8}!utils.\+ino@{utils.\+ino}}
\subsubsection[{\texorpdfstring{percent8(uint8\+\_\+t full, uint8\+\_\+t fac)}{percent8(uint8_t full, uint8_t fac)}}]{\setlength{\rightskip}{0pt plus 5cm}uint8\+\_\+t percent8 (
\begin{DoxyParamCaption}
\item[{uint8\+\_\+t}]{full, }
\item[{uint8\+\_\+t}]{fac}
\end{DoxyParamCaption}
)}\hypertarget{utils_8ino_ae7f706e9934c4154b7a4e222f14c8c9a}{}\label{utils_8ino_ae7f706e9934c4154b7a4e222f14c8c9a}

Definition at line 23 of file utils.\+ino.

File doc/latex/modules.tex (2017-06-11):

\section{Modules}
Here is a list of all modules\+:\begin{DoxyCompactList}
\item \contentsline{section}{Buttons}{\pageref{group__buttons}}{}
\item \contentsline{section}{Car Basics}{\pageref{group__car}}{}
\item \contentsline{section}{Knight Rider}{\pageref{group__knightrider}}{}
\item \contentsline{section}{Police}{\pageref{group__police}}{}
\item \contentsline{section}{Rainbow}{\pageref{group__rainbow}}{}
\item \contentsline{section}{Speed}{\pageref{group__speed}}{}
\item \contentsline{section}{Deployment}{\pageref{group__deployment}}{}
\item \contentsline{section}{Main}{\pageref{group__main}}{}
\item \contentsline{section}{Fast\+L\+ED}{\pageref{group___fast_l_e_d}}{}
\item \contentsline{section}{Adafruit\+\_\+\+Neo\+Pixel examples}{\pageref{group___adafruit}}{}
\end{DoxyCompactList}

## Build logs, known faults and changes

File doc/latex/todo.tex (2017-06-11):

\begin{DoxyRefList}
\item[\label{todo__todo000002}%
\hypertarget{todo__todo000002}{}%
Global \hyperlink{group__car_ga6b1fd674445dd1c654dfe8b8b65f168e}{beam} (unsigned long state)]Rewrite as all L\+E\+Ds get clear at the beginning of the main loop  
\item[\label{todo__todo000001}%
\hypertarget{todo__todo000001}{}%
File \hyperlink{car__basics_8ino}{car\+\_\+basics.ino} ]Write a function for brake lights.  
\item[\label{todo__todo000003}%
\hypertarget{todo__todo000003}{}%
File \hyperlink{police_8ino}{police.ino} ]May add more flasher. 

Extract beacon light as separate function.  
\item[\label{todo__todo000004}%
\hypertarget{todo__todo000004}{}%
File \hyperlink{rainbow_8ino}{rainbow.ino} ]Make period of rainbow cycle configurable in \hyperlink{config_8h}{config.\+h}  
\item[\label{todo__todo000005}%
\hypertarget{todo__todo000005}{}%
File \hyperlink{speed_8ino}{speed.ino} ]Write a function that detects braking via negative acceleration. 
\end{DoxyRefList}

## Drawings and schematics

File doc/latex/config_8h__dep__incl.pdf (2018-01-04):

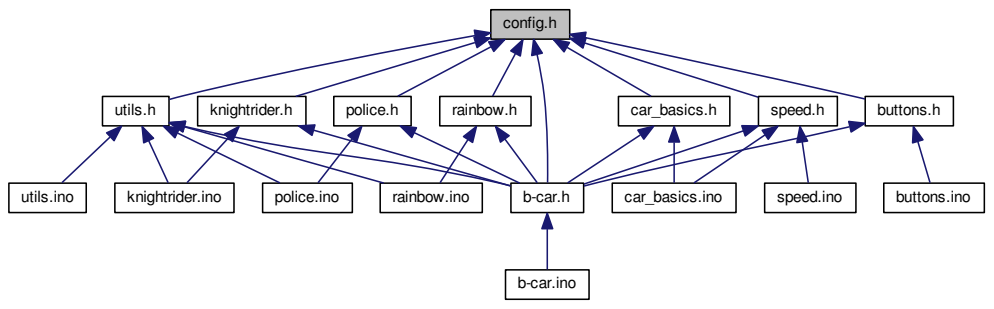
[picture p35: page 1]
config.h; b-car.h; utils.h; knightrider.h; police.h; rainbow.h; car_basics.h; speed.h; buttons.h; b-car.ino; utils.ino; knightrider.ino; police.ino; rainbow.ino; car_basics.ino; speed.ino; buttons.ino

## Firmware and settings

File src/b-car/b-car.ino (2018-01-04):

/**
 * @file b-car.ino
 * @author copyrights
 * @brief Main file.
 * @ingroup main
 */
#include <Adafruit_NeoPixel.h>
#include "b-car.h"

/**
 * @ingroup main
 * @{
 */
Adafruit_NeoPixel strip = Adafruit_NeoPixel(NUM_LEDS, PIN, NEO_RGB + NEO_KHZ800);
byte mode = 0;
volatile unsigned long time;
/**
 * @brief Initial setup.
 */
void setup() {
  // This is for Trinket 5V 16MHz, you can remove these three lines if you are not using a Trinket
  #if defined (__AVR_ATtiny85__)
    if (F_CPU == 16000000) clock_prescale_set(clock_div_1);
  #endif
  // End of trinket special code
  pinMode(BUTTONS1, INPUT);
  pinMode(BUTTONS2, INPUT);
  
  strip.begin();
  strip.show();
  setup_interrupt();
}

/**
 * @brief Main loop
 */
void loop() {
  
  updateButtons();
  time = millis();
  if(mode == 0){
    normalmode();
  }
  else if (mode == 1)
  {
    rainbowmode();
  }                                                     
  if (getRising(S1)>0)
  {
    mode=(mode+1)%2;
    resetspeed();
  }
  strip.show();
}

/**@}*/

/**
 * @brief Normal operation mode.
 * @ingroup car
 */
void normalmode(){
  unsigned long beamstate=0;
  clearAll();
  //Button5 low beam 
  if(buttonState(S5)){
    beamstate=LOWBEAM;  
  }
  //Button4 high beam
  if(buttonState(S4)){
    beamstate=HIGHBEAM;
  }
  //Button7 white
  if (buttonState(S7))
    beam(beamstate);
  
  //Button2 turn right
  if(buttonState(S2))
    turn_right();
    
  //Button3 trun left
  if (buttonState(S3))
    turn_left();
  
  //Button6 red
  if(buttonState(S6))
    knightrider();
  
  tacho();
  //Button8 black
  if(buttonState(S8))
    underbody_rb();
  //Button 9 kill switch
  if (buttonState(S9))
    police();
  //Button 10 horn
  if (buttonState(S10))
    flash();
  
  if(braking())
    brakelight();
}

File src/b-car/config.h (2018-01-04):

/**
 * @file config.h
 * @brief Adjust your settings here.
 *
 * Create a custom.h file and copy line 15 to second last line of config.h to it. Then uncomment line 10 of config.h file.
 * @author copyrights
 */
#ifndef CONFIGH
#define CONFIGH
#include <Arduino.h> 
#ifdef __AVR__
  #include <avr/power.h>
#endif
#include <Adafruit_NeoPixel.h>
/* uncomment the next line to use custom settings instead of mine */
//#define CUSTOM

#ifdef CUSTOM
#include "custom.h"
#else
/**
 * @defgroup buttons Buttons
 * @brief Use R-2R resistor ladder network for more buttons.
 * 
 * @{
 */
/** @brief Define analog input for first five buttons. */
#define BUTTONS1 A1
/** @brief Define analog input for second five buttons. */
#define BUTTONS2 A2
/** @brief Define delay in ms to debounce button presses.*/
#define DEBOUNCE 20

/** @brief Bit mask for button 5 */
#define S5  0b0000000001
/** @brief Bit mask for button 4 */
#define S4  0b0000000010
/** @brief Bit mask for button 3 */
#define S3  0b0000000100
/** @brief Bit mask for button 2 */
#define S2  0b0000001000
/** @brief Bit mask for button 1 */
#define S1  0b0000010000
/** @brief Bit mask for button 10 */
#define S10 0b0000100000
/** @brief Bit mask for button 9 */
#define S9  0b0001000000
/** @brief Bit mask for button 8 */
#define S8  0b0010000000
/** @brief Bit mask for button 7 */
#define S7  0b0100000000
/** @brief Bit mask for button 6 */
#define S6  0b1000000000

/** @brief Bit mask for simulated toggle buttons. */
#define TOGGLEMASK 0b1110000000

/**@}*/

/**
 * @defgroup car Car Basics 
 * @brief Basic car functionality.
 * 
 * @{
 */
/** @brief Color of turn lights. */
#define TURNLIGHT 0xffc000
/** @brief Color of low beam. */
#define LOWBEAM 0x3f3f3f
/** @brief Color of high beam. */
#define HIGHBEAM 0x7f7f7f
/** @brief Color of back lights. */
#define BACKLIGHT 0x3f0000
/** @brief Color of brake lights. */
#define BRAKELIGHT 0xff0000
/** @brief time brake lights glow in ms. */
#define BRAKETIME 1000
/**@}*/

/**
 * @defgroup knightrider Knight Rider
 * @brief A Knight Rider like front row.
 * 
 * @{
 */
/** @brief Red part of Knight Rider like front row. */
#define KRR 0x7f
/** @brief Green part of Knight Rider like front row. */
#define KRG 0x00
/** @brief Blue part of Knight Rider like front row. */
#define KRB 0x00
/** @brief Period in ms the Knight Rider like front row needs to move in one direction. */
#define KRPERIOD 500
/** @brief Fade out period in ms for a smooth light flow. */
#define KRDTZ 200
/**@}*/

/**@defgroup police Police
 * @brief Police beacon light and front flash.
 * @{
 */
/** @brief Red part of the police beacon light.*/
#define PR 0x00
/** @brief Green part of the police beacon light.*/
#define PG 0x00
/** @brief Blue part of the police beacon light.*/
#define PB 0xff
/** @brief Rotation period in ms of the police beacon light.*/
#define PPERIOD 1000
/** @brief Fade out period in ms for a smooth light flow. */
#define PDTZ 200
/** @brief Left side flash color of the police front row.*/
#define PLFLASH 0xff0000
/** @brief Left side low light color of the police front row.*/
#define PLLOW 0x1f0000
/** @brief Right side flash color of the police front row.*/
#define PRFLASH 0x0000ff
/** @brief Right side low light color of the police front row.*/
#define PRLOW 0x00001f
/**@}*/

/**@defgroup rainbow Rainbow
 * @brief Puts rainbow color to the LEDs.
 * @{
 */
/** @brief Rainbow step size between two LEDs. */
#define RBSTEP 40
/** @brief If defined more functions are added to rainbow mode. */
//#define MORERAINBOW
/**@}*/

/**
 * @defgroup speed Speed
 * @brief Measure speed by interrupts.
 * 
 * @{
 */
#define INTERRUPTPIN PCINT1 //!< This is PB1 per the schematic
#define PCINT_VECTOR PCINT0_vect  //!< @note This step is not necessary
#define DATADIRECTIONPIN DDB1 //!< @see Page 64 of data sheet
#define PORTPIN PB1 //!< @see Page 64
#define READPIN PINB1 //!< @see Page 64
/**@}*/

/**
 * @defgroup deployment Deployment
 * @brief Deployment of LEDs.
 * 
 * @{
 */
 
/** PIN is the data pin for LEDs control.*/
#define PIN 0
/** NUM_LEDS is the count of LEDs use in b-car.*/
#define NUM_LEDS 32
extern const byte turn_light_left[2];
extern const byte low_beam_row[4];
extern const byte high_beam_row[4];
extern const byte front_row[5];
extern const byte tacho_row[7];
extern const byte turn_light_right[2];
extern const byte down_left_row[4];
extern const byte down_right_row[4];
extern const byte back_light_row[4];

extern const byte rainbowrow_left[17];
extern const byte rainbowrow_right[17];

extern Adafruit_NeoPixel strip;
/**@}*/

/**
 * @defgroup main Main 
 * @brief Main program.
 * 
 * @{
 */
 
/**
 * @brief Global accessible variable that stores the current time after program start in ms.
 * @see millis()
 */
extern volatile unsigned long time;

/** @brief stores current operation mode */
extern byte mode;
/**@}*/
#endif
#endif

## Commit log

2017-04-23 commit current development status. waiting for additional parts to be integrated.
2017-05-18 * add hardware design * more functions * Update README.md
    [b-car_pcb_layout_rev1.fzz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]
2017-05-20 * fix error in schematic. * fix "I haven't pressed save button" in tacho function. * move constants and defines to config.h for better portability.
    [b-car_schematic.fzz]
2017-05-21 change button handling
2017-05-30 * add working tachometer for range from 0.4 to about 25 km/h * turn off light button (my motorcyle armature only allows switching between low and high beam) * update button name to pcb design * clean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
2017-06-05 * more images * fix typos * new gif
    [b-car.ino, buttons.ino, car_basics.ino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]
2018-01-04 * Compile b-car direct without arduino. * Brake lights * some documentation
